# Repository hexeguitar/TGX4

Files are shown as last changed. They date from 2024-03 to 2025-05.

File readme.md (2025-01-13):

## TGX4 - Teensy Guitar Amp Project
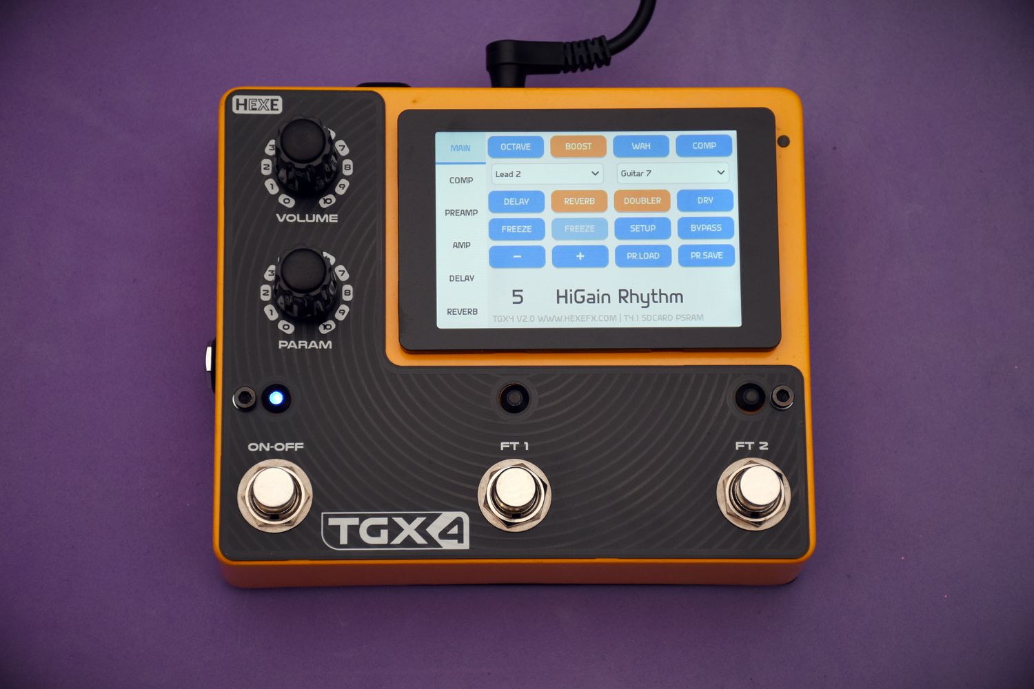
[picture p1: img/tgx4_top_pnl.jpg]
Top View
  

This project aims at creating a nice usable set of guitar and bass tones while using relatively inexpensive hardware and being simple to build.  
It combines a Neural Network amp modeler with stereo IR cabinet emulation, versatile stereo Ping-Pong delay and 3 different reverbs. There is also a Compressor, Wah and Booster with octave up mode for further input tone shaping.  

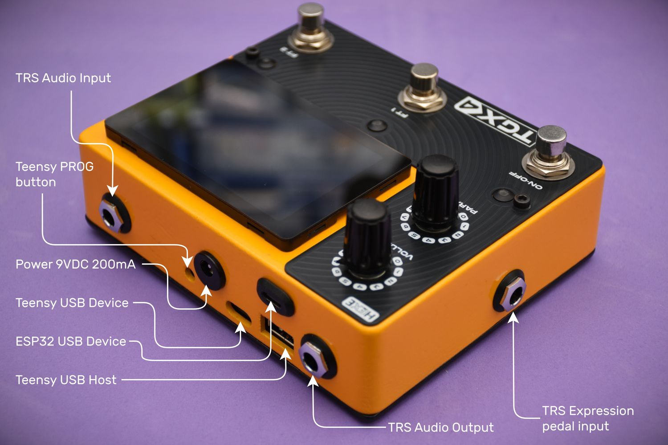
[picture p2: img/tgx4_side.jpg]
Side View
  

### Change-log  
V2.1 - 12-2024 - Added Front Panel, bug fixes  
V2.0 - 07-2024 - Dedicated hardware platform  
V1.4 - 04.2024 - Multiple hardware platforms added  
V1.3 - 03.2024 - Initial release.  

### User Interface  
#### HTML webpage
In general all the parameters are controlled via MIDI. There is a lot of controls and to make the hardware less expensive and easier to build the starting point is a simple html page using WebMIDI + WebSerial, which, opened in one of the supported browsers (Chrome, Opera, Edge) offers a full GUI interface.  
Teensy is using the USB Serial port to show the status and other info about the current state.  
Usage:  
1. Plug the Teensy with uploaded firmware into the USB port.
2. Open the TGX4.htm page (html folder) in any of the supported browsers.
3. Choose Teensy MIDI for the MIDI interface.
4. Click _Connect_ and choose the Teensy Serial port.
5. Press _Term_ button to switch between the status report and the CLI.
6. Use dials and buttons to control the effects.  

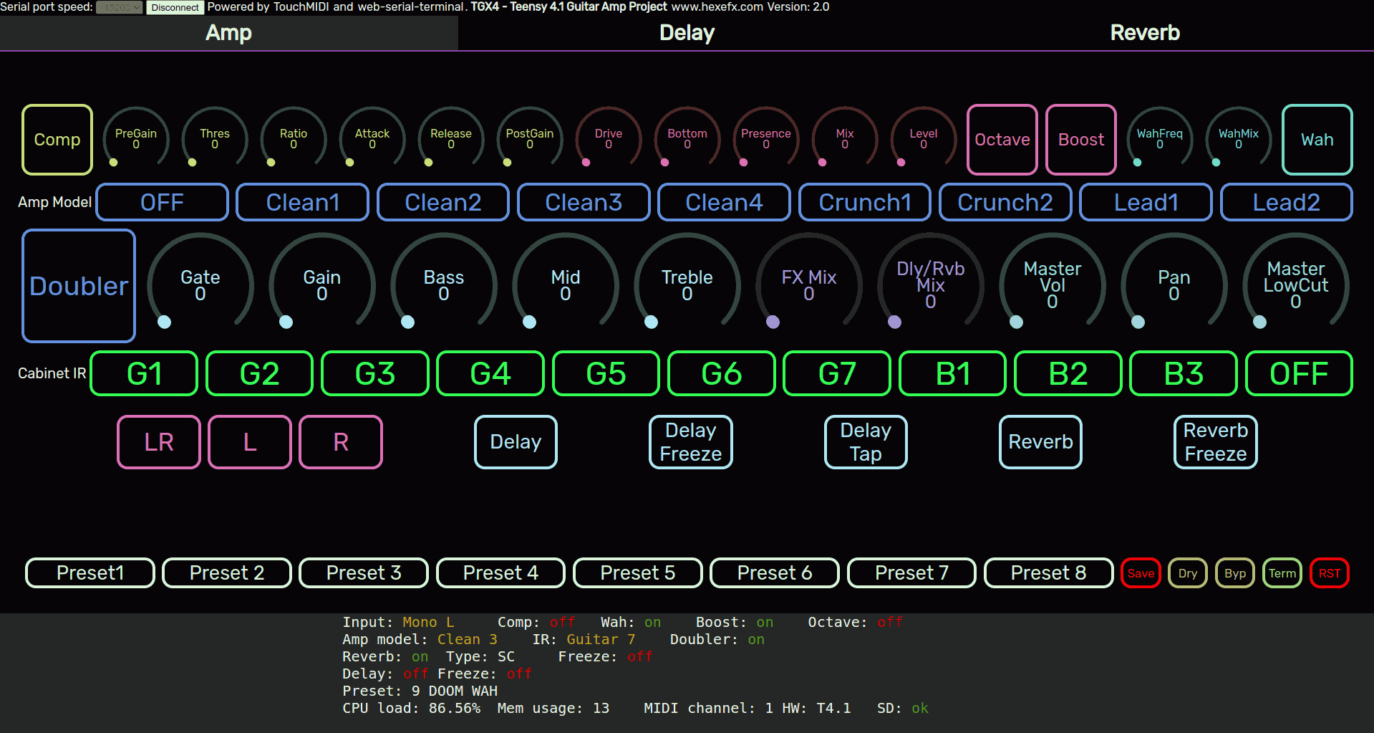
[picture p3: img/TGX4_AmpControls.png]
Ampinterface
  

#### Touchscreen GUI  
A separate project is provided for the **WT32SC01Plus board** (ESP32-S3 + 3.5" 480x320 IPS display, capacitive touchscreen) which is the main and dedicated user interface allowing access to all controls and functions of the pedal.  
The GUI is created using LVGL9 library:    

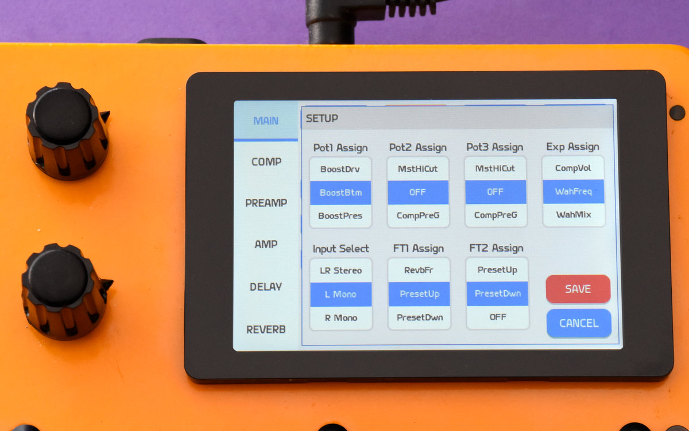
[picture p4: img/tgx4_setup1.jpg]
Setup
  
### Internal structure 

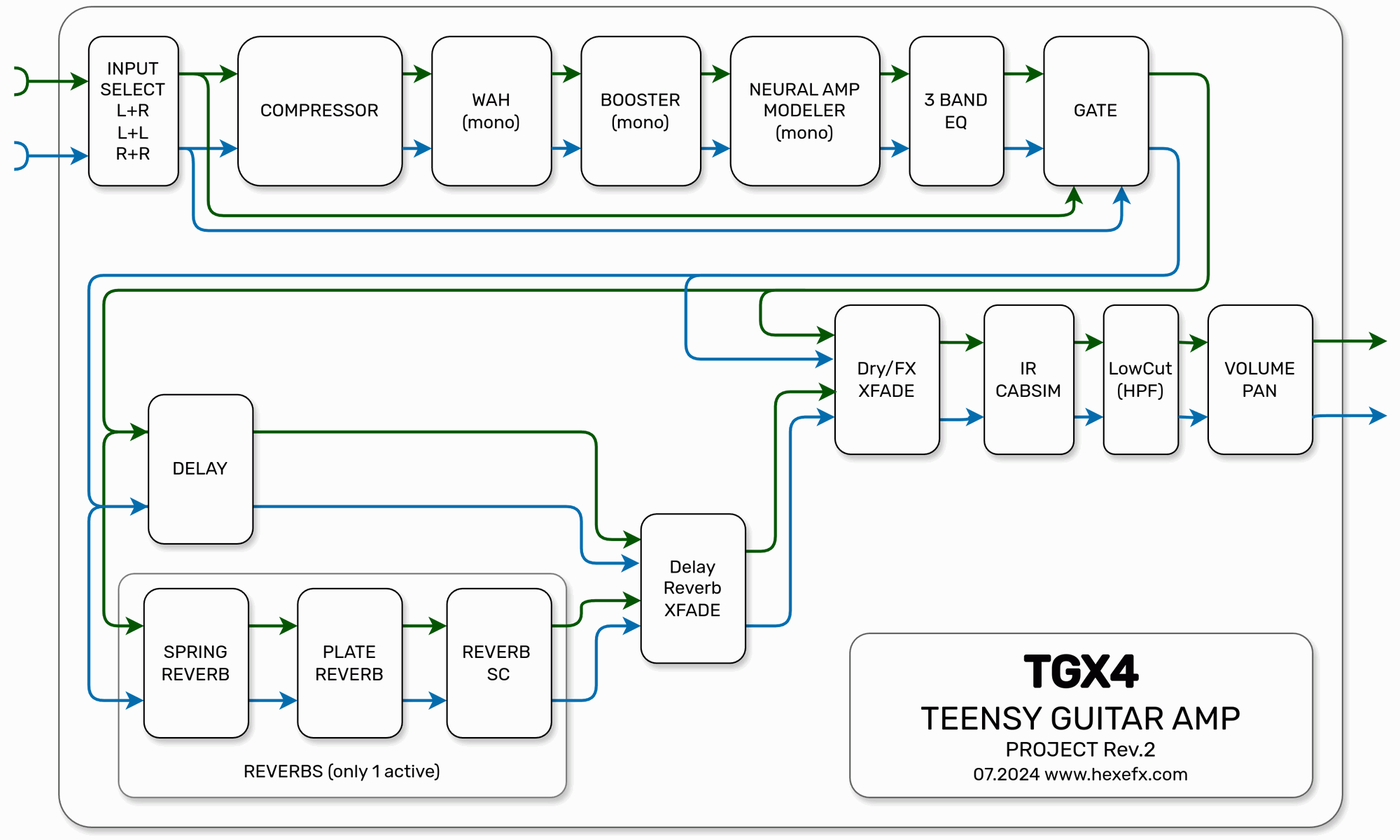
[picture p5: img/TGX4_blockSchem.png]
Internal structure
  

## Signal Flow  
The signal flow, except three components is stereo. The three mono components are: **Wah**,  **Booster** and **Neural Amp Modeler**. Mono means, these two sum the input signal into one and send one output to both L and R channels when enabled. In bypass mode both mono blocks pass the stereo signal unaffected. This way the TGX4 can be used either with mono source or as stereo effects processor (with Wah,  Booster and Amp Modeler disabled).
1. **Input Select** - controls which input channel use as source:  
	* L+R - stereo input
	* L+L - left mono input
	* R+R - right mono input
2. **Compressor** - stereo dynamic compressor with wide variety of controls:  
	* Pregain - input gain  
	* Threshold  
	* Ratio  
	* Attack, Release  
	* PostGain (MakeUp)  
3. **Wah** - mono wah implementation:  
	* 8 available models  
	* Frequency control  
	* Mix - dry/wet mixer  
4. **Booster** - an oversampled wave shaper based on 12AX7 tube curve:  
	* Drive - overdrive level  
	* Bottom - input highpass filter  
	* Presence - treble control  
	* Mix - dry/wet(distorted) mixer ratio, useful for Bass!  
	* Level - Booster output volume
	* Octave - analog octave up emulation  
5. **Neural Amp Modeler** 8 models available, from, clean channels, through light crunch to high gain lead ones:
	* Gain - controls the input signal level
6. **3 Band EQ** - this EQ is a "passive" one, meaning the flat response is when all controls are at max. Use for slight tone adjustments. Most of the "amp" sounds are already modelled in the previous block.  
7. **Gate** - adjustable Noise Gate. Noise gate is using the clean input signal for the side chain path, this way the threshold does not have to be adjusted for different distortion levels.
8. **Time Based FX Section** consisting of two effects in parallel: Stereo Ping-Pong delay with modulation and one of 3 available Reverbs. There are two main controls for this section:  
	* FX Mix - controls the dry sound vs Time FX sound mix ratio. Use to set the balance between the main sound and the Delay + Reverb combo  
	* Delay/Reverb Mix - this mixer controls the balance between the delay and reverb outputs.
9. **Stereo Cabinet Emulator / IR convolver**:  
	* 7 guitar cabinet models  
	* 3 bass cabinet models  
	* Stereo Doubler function emulating double tracking  
10. **Output Section**:  
      * Master Lowcut - output highpass filter to control the low end range  
      * Pan - Left/Right panorama setting  
      * Volume - final output volume   
  
### Stereo Ping-Pong delay  
One of the time based effects, versatile 1 second delay with modulation and Freeze feature (looper mode). Controls:  
   * Time - delay time  
   * Inertia - how fast the delay time is updated after change. Creates weird pitch shifting effects  
   * Repeats - amount of feedback  
   * HiCut - low pass filter inside the delay path, controls the treble loss for each repeat. Many delays implement such feature and claim to make the sound "analog"  
   * LowCut - high pass filer inside the delay path, controls the bass loss for each repeat  
   * Treble - overall treble control to make the sound darker
   * Bass - output bass control for further delay tone shaping  
   * ModRate - modulation rate (internal LFO speed)
   * ModDepth - modulation depth (internal LFO depth)
   * Tap Tempo  
   * Freeze mode - mutes the input signal and lets the echo repeat infinitely  

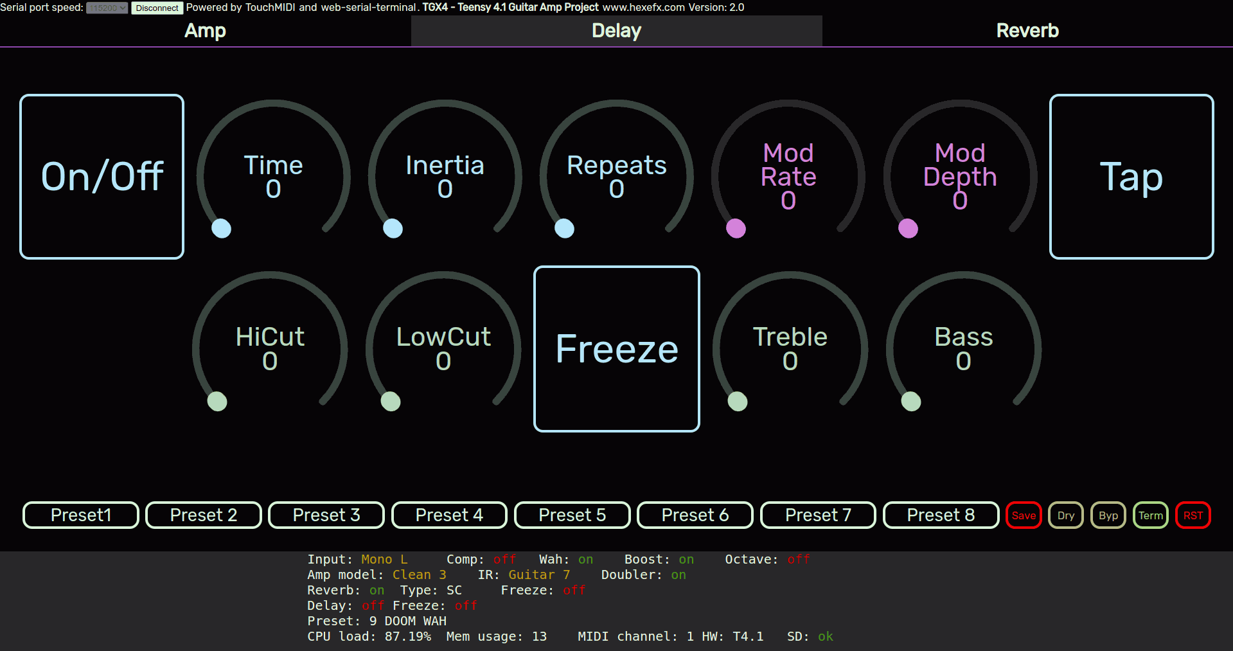
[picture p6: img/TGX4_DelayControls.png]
Delay controls
     

## Reverb Section  
There are 3 types of reverb built in, **only one can be active** at a time:  
1. **Plate Reverb** - versatile lush sounding long reverb:  
	* Size - reverb time  
	* Diffusion - lower values create more echo effects inside the reverb tail  
	* Treble Cut - treble loss in the reverb tail, affects the reverb time  
	* Bass Cut - bass loss in the reverb tail, affects the reverb time  
	* Treble - output treble control for the reverb wet signal  
	* Bass - output bass controls fot the reverb wet signal  
	* Pitch - reverb pitch set in semitones (range -12 to +24)  
	* Pitch Mix - mix ratio for the pitched up/down and natural pitch signal (creates harmonies)  
	* Shimmer - amount of shimmer effect  
	* Pitch Shim - shimmer effect pitch setting  
	* Freeze mode - creates infinite reverb sound  
	* Bleed In - amount of input signal fed into the reverb while in Freeze mode.  
2. **Reverb SC** based on Sean Costello's reverb algorithm using multiple feedback delay lines *(available only with PSRAM installed)*:  
	* Time - reverb time  
	* Lowpass Freq - tail treble loss  
	* Freeze mode - infinite reverb sound  
3. **Spring Reverb** - for more classic guitar tones, emulation of a typical spring reverb tank:  
	* Time - reverb time  
	* Bass Cut - high pass filter
	* Treble Cut - lowpass filter  

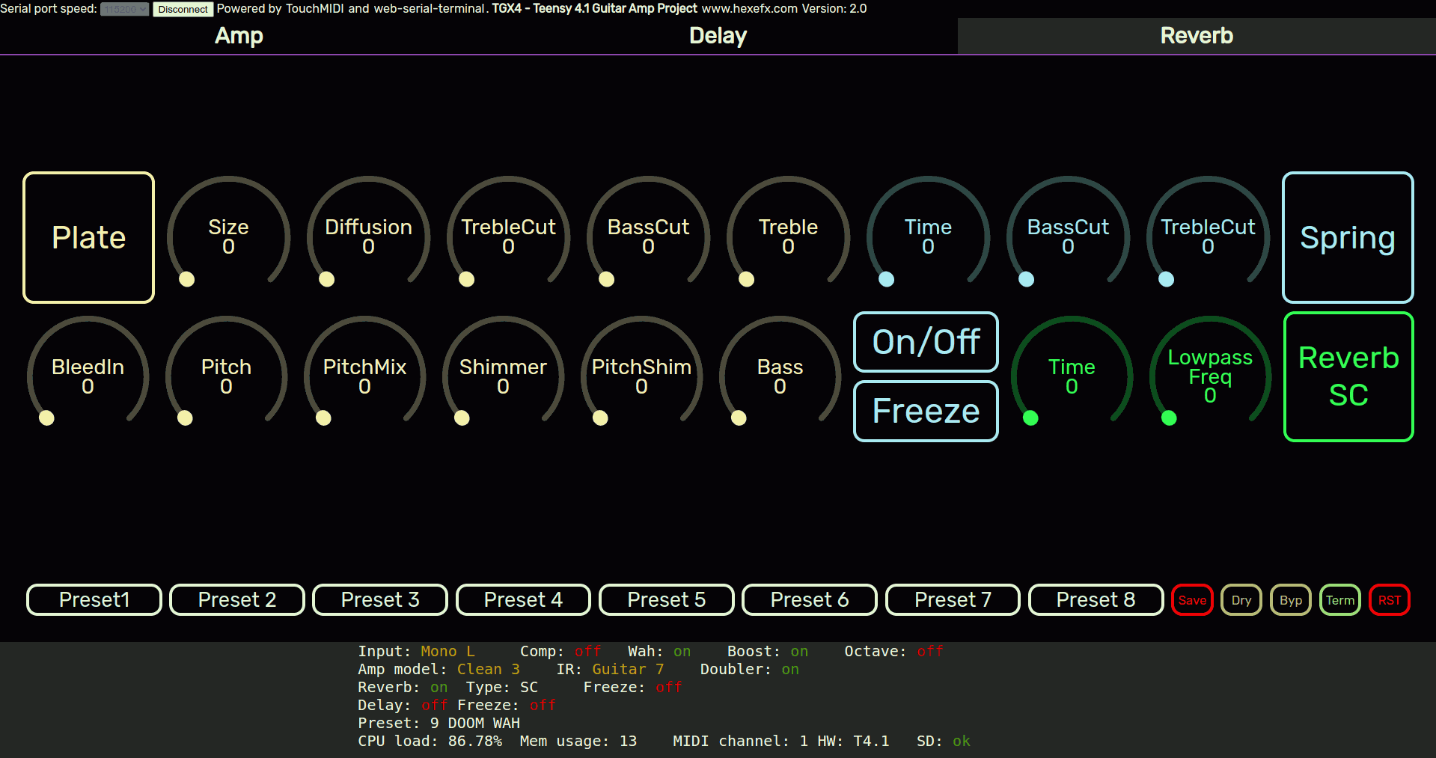
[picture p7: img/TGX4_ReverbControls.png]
Reverb controls
   

Press **Plate**, **Spring** or **ReverbSC** button to activate the reverb.  

## Hardware  
In the simplest form, this project can run on a Teensy 4.0 or T.4 and the audio adapter board.  
Adding PSRAM to the Teensy4.1 opens up the full set of features. Lack of PSRAM results in:  
- ReverbSC disabled,
- Delay has a shorter time range.  
  
Recommended upgrade would be a high impedance input buffer using an opamp or even a simple transistor one.  
See [**here**](diy_buffer.md) for a simple DIY project. 
Alternatively, another pedal with buffered bypass can be used instead.  

The hardware build option is set either in the `platformio.ini` file  
`default_envs = t40_audio_board`  
or by invoking the build command from the terminal:  
`pio run -e t40_audio_board`  

List of pre configured hardware platforms as of July 2024:  
- `hexefx_tgx4` - Dedicated hardware platform for this project using 32bit AKM converters.
- `t40_audio_board` - Teensy4.0 + Audio Adaptor Board  
- `t41_audio_board` - Teensy4.1 + Audio Adaptor Board 
- `t40_blackaddr_tgapro` - Blackaddr TGA Pro + Teensy4.0  
- `t41_blackaddr_tgapro` - Blackaddr TGA Pro + Teensy4.1   
 
The project is designed to be easily adaptable to many Teensy based hardware platforms, take a look [**here**](hw_platform.md) for more details.  
### Caution!  
A high gain sound, like the Preset 5 might and do create a feedback and oscillation on some of the hardware platforms, namely the SGTL5000 and ES8388. The noise gate can cut it off, although some oscillation will be audible when the gate closes.  WM8731 seems to be more immune to oscillations.  
A very high gain devices require a careful layout and design to make them as silent as possible. It is also a reason for designing a dedicated HW platform for the TGX4 project which incorporates design techniques to minimize these issues.  
## TGX4 Hardware  
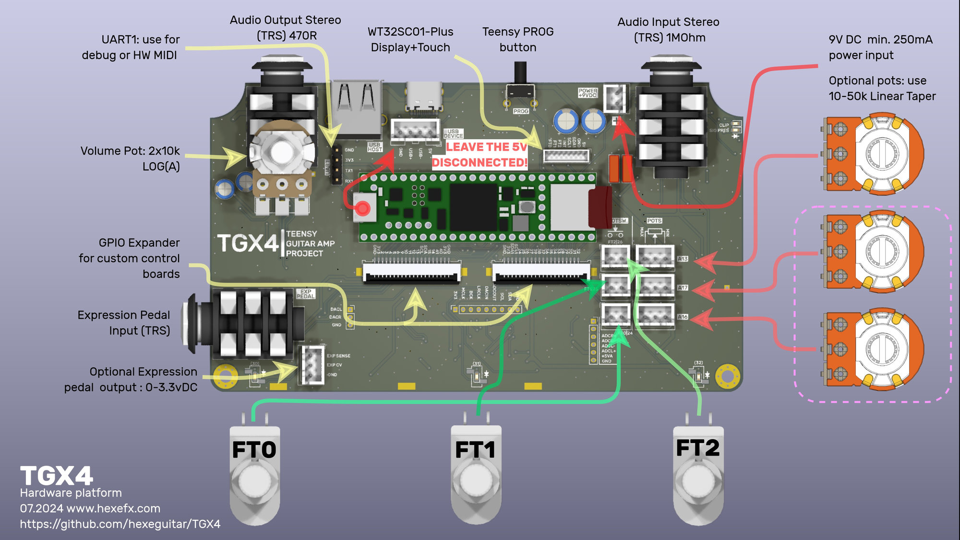
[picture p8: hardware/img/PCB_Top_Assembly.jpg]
   
 Dedicated TGX hardware platform project is available in the `hardware/`  folder.  

## Usage  
1. Open the **TGX4_TeensyMainBoard** project in the PlatformIO environment.
2. Open the `platformio.ini` file and set the required hardware configuration.
3. Build the project and upload it to the Teensy4 board.
4. Open the **TGX4_WT32SC01PLUS_GUI** project in the PlatformIO environment.
5. Build the project and upload it to the Display board.
6. For the web page access open the `TGX4.html` file placed in the `html` folder in Chrome, Chromium or Edge browser (others do not implement WebMIDI and WebSerial).
7. Connect to the USB MIDI interface listed as Teensy.  
8. Click `Connect` button on the top of the page and choose Teensy Serial port.
9. Use the dials and buttons to control the device.  

## Preset System (no display version)
A snapshot of all controls (except Delay+Reverb Freeze modes) can be saved in 128 available preset slots. Preset System is using the SD card to store the files. If no SD card is detected, the number of presets is limited to 8, stored in EEPROM.
1. Choose the Preset slot by pressing the buttons **Preset 1** - **Preset 8**. Alternatively use the CLI console to load preset numbers over 8 using the command `preset-load n`, where `n` is the preset number in range 1-128.
2. Set a new name for the preset using the `preset-name xxxx` CLI command.
3. Press **Save** to store the current sound in the chosen preset.  

## Preset System (using the display GUI)  
Switching the presets can be done in two ways:  
1. Using the **+** and **-** buttons on the touch screen MAIN page. The new preset is loaded immediately. To reload the preset from the saved file (ie. restore to saved version) press the **PR.LOAD** button.
2. Using the footswitches. The default function of the middle footswitch is **Preset UP**, the right one **Preset DOWN**. Pressing one of the footswitches enables browsing through the presets without loading them. To activate the chosen preset press and hold down one footswitches (usually the last used one). Browsing is shown as a popup window with the number and the name of the preset.  
   
## Default Presets  
1. Clean guitar sound, spring reverb.
2. Lightly overdriven clean guitar sound with modulated delay used as a stereo chorus.  
3. Boost/Overdrive into Clean channel + Reverb SC. Uses Stereo Doubler to emulate double tracking. Bluesy rhythm tone.  
4. Crunch Amp + Boost, mono mode + stereo delay and reverb. Bluesy solo sound.
5. High gain rhythm tone, a bit of Spring Reverb, Stereo Doubler enabled.  Uses Booster for input tone shaping, low end cut and light overdrive.
6. High Gain solo tone with modulated delay and reverb.  
7. Clean Bass sound with compressor.
8. Distorted fuzzy stereo bass sound.  

## Demos  
https://www.youtube.com/watch?v=2hztEZ9_kYk  
Watch the video (https://youtu.be/2hztEZ9_kYk)  

https://www.youtube.com/watch?v=AlLRwmOwigU  
Watch the video (https://youtu.be/AlLRwmOwigU)  

All guitar/bass sounds on this track were recorded using the TGX4:    


## Command Line Interface  
Use the **Term** button places on the main **Amp** page to switch between the status report and the CLI. Type `help` to list all the commands. CLI uses history and autocomplete.  
Available commands:  
- `preset-rst` - repopulates the 128 (or 8 without the SD card) available presets with default "factory" ones.  
- `preset-name` - sets the new name for the current preset. Argument: name, max 15 chars. Eg. `preset-name Solo-Delay`
- `preset-load` - loads the preset, argument: preset number 1-128.
- `preset-backup` - creates a copy of the 128 presets data in a separate `backup` directory on the SD card.
- `meminfo`- print RAM memory details  
- `load`- list CPU loads for all components  
- `midi-ch`- assign a new MIDI channel for the Teensy. Use it when controlling the device with other MIDI controllers. The WebMIDI interface sends the data on channel 1.  
- `i2c` - I2C scanner, takes one parameter: 0, 1 or 2 (Wire, Wire1, Wire2) and reports all found devices.
- `list` - lists all the files found on the SD card.

## Credits  
The Neural Network Modeler is based on implementation by [Keith Bloemer/GuitarML](https://github.com/GuitarML/Seed)  

[OpenAudio_ArduinoLibrary](https://github.com/chipaudette/OpenAudio_ArduinoLibrary) by Chip Audette  

[embedded_cli](https://github.com/funbiscuit/embedded-cli) by Sviatoslav Kokurin.

---  
(c) 2024 by Piotr Zapart  
www.hexefx.com

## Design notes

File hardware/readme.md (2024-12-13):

## TGX4 Dedicated Hardware Platform  
### Features:  
- Stereo input/output, electronic (FET) bypass  
- Analog Dry/Wet mixer  
- 32bit 44.1kHz ADC + DAC
- Optional codec module replacing the default ADC+DAC  
- Flexible control interface options, default: TFT+Touch screen (W32SC01_plus)  
- Analog signal presence and clip indicator  
- Teensy4.1 as main DSP
- Expression pedal input (can be used as 0-3.3V CV input)
- 3 configurable footswitches
- up to 3 configurable pot (default: 1)  
- 3 leds  
- USB device (MIDI + Serial - Teensy)
- USB host
- Enclosure: Hammond 1590XX  
---  
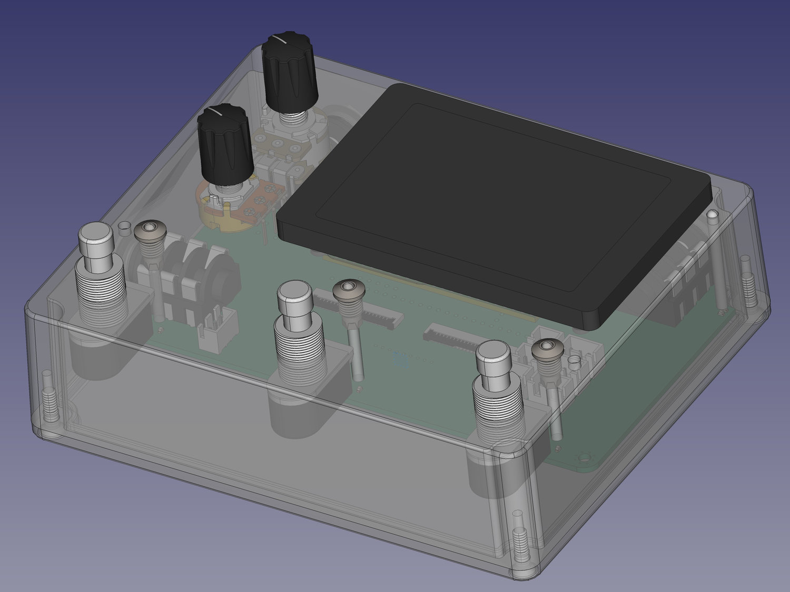
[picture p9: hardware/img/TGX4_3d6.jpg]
  
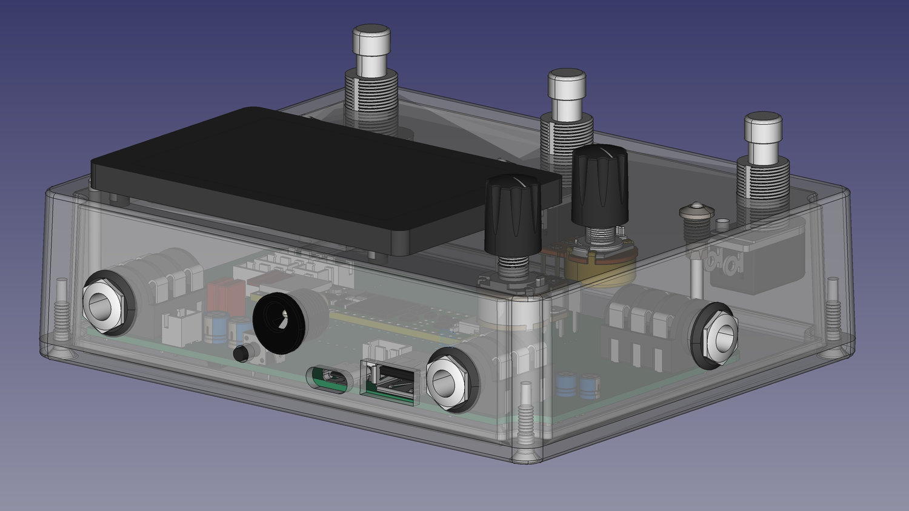
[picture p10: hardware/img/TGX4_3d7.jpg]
  
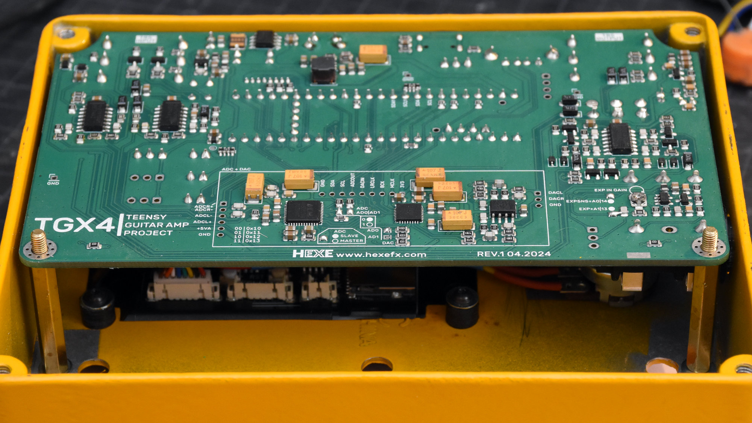
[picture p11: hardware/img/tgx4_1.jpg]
  

### Assembly  
  
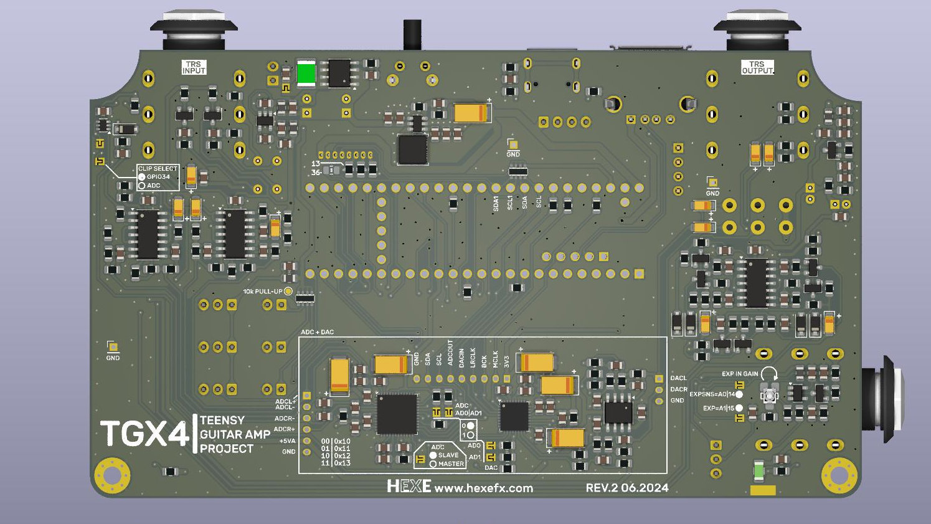
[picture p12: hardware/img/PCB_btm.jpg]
  

### Building  
#### 1. Main PCB  
KiCad project is provided in the `KiCad_proj/MainBoard` folder.  
The main PCB is a 4 layer one. A zip file with Gerbers is included and can be used to order a set of the boards. I do recommend ordering a stencil for the bottom layer.  
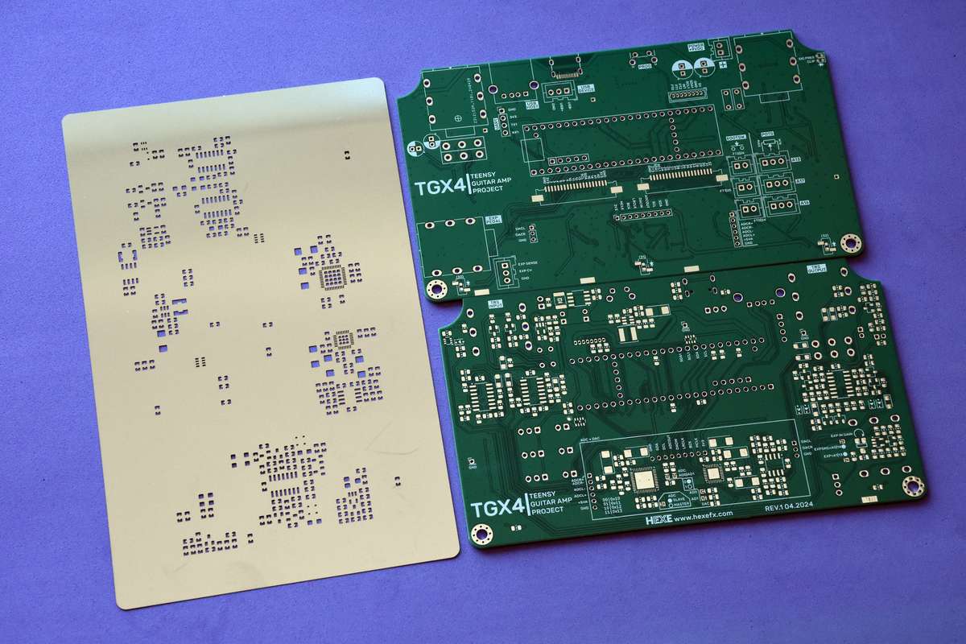
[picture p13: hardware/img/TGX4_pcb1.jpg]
  

Interactive HTML BOM is available and will help with hand placing the components. Most of the passives are 0805 and larger.  
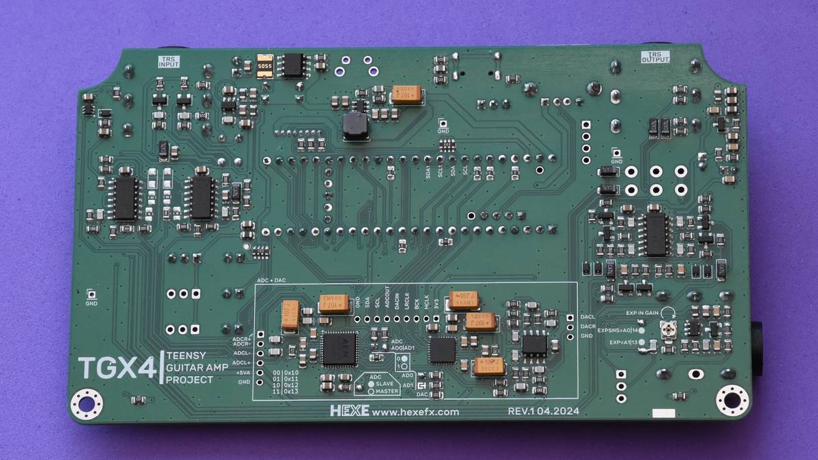
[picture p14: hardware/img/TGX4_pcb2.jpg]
  

There are various jumpers included on the main PCB. They are pre-set for default configuration.
1. **CLIP SELECT** The AK5552 ADC has an input signal clip indicator which is used to drive the red part of the SignalPresence/Clip indicator. This might not be the case for other codecs/ADCs. Signal Clip line can be also driven directly from Teensy's **GPIO34**. To enable it the jumper has to be bridged. Default source is the ADC.  
2. **ADC MASTER/SLAVE** selector. Default setting is Slave - Teensy generates all the required I2S clocks.  
3. **ADC ADDR** I2C address used to configure the AK5552 chip.  
4. **DAC ADDR** I2C address used to configure the AK4452 chip. 
5. **13/36** near the display connector. Footswitch signals are routed to the ESP32S2 board, one can be swapped for the GPIO36 and used for other tasks.  
6. **EXPSNS=A0|14** Expression pedal detection is routed to GPIO14 (default). To free the GPIO14 when no expression pedal is used, make the jumper open.  
7. **EXP=A1|15**  Expression pedal signal. By default routed to GPIO15 (jumper closed).  
8. **10k PULL-UP** a test point providing a 10k 3.3V pull up resistor in case it's needed. 

Top layer are mainly through-hole components, except the USB-C connector for the Teensy and the LEDs.  
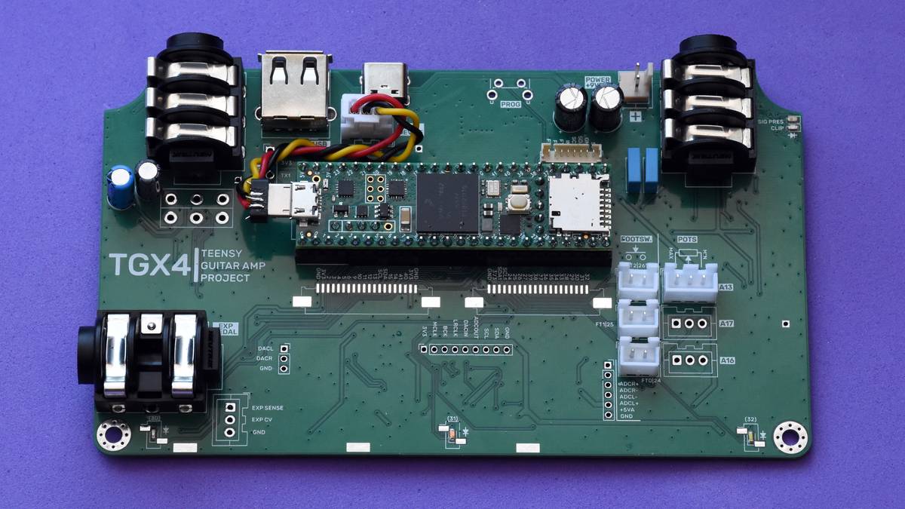
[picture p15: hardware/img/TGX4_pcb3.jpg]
 
### Caution!  
<h2><span style="color:red;">While connecting the Teensy and the ESP32 to the USB sockets leave the VBUS 5V wire disconnected!</span></h2>  

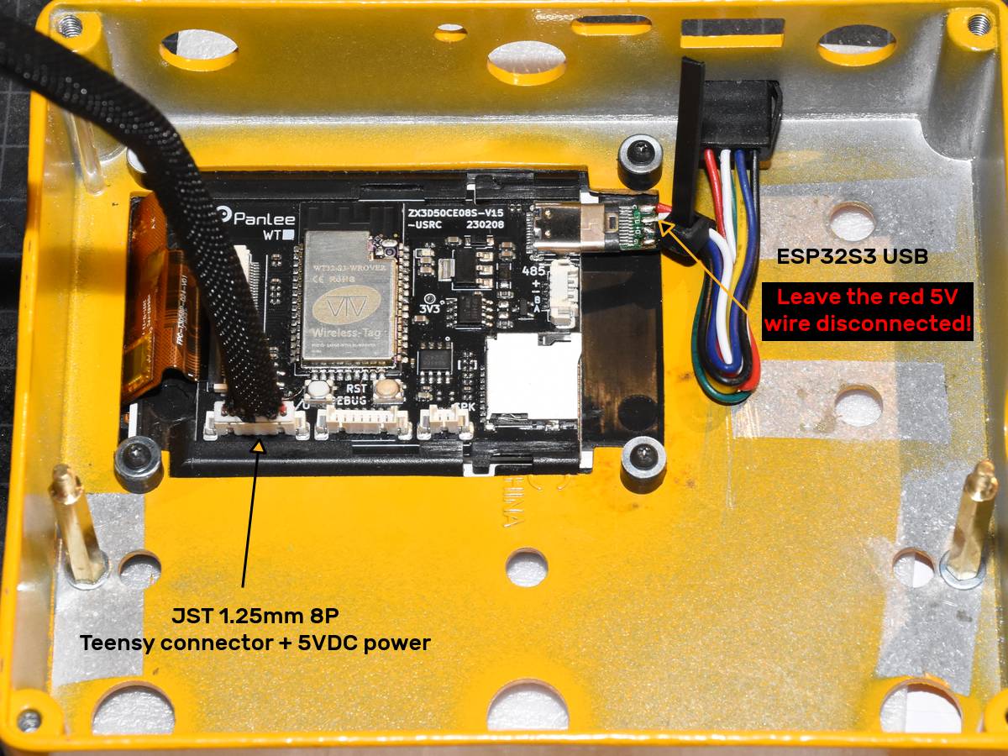
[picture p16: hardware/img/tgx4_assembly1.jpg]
 
#### 2. Making the enclosure  
See [>>>> here <<<<](enclosure.md).  

### Front Panel  
Front panel as KicaD PCB project, including gerbers is available in the `KiCad_proj/FrontPanel` folder.  
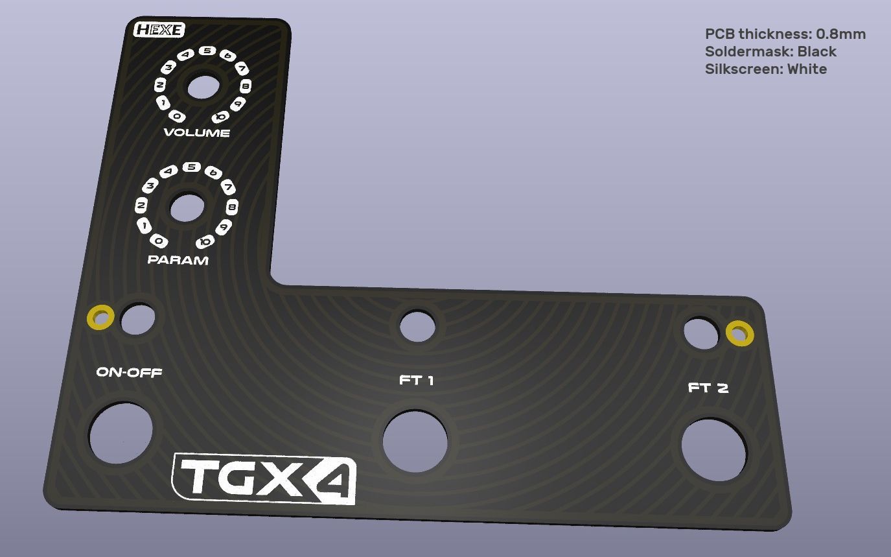
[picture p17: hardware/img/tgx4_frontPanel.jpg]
   

### Display  
The ESP32S3 + Touch display board used in this project is the WT32SC01Plus. There are many variants of the ESP32+display boards floating around, here are the specs of the used one:  
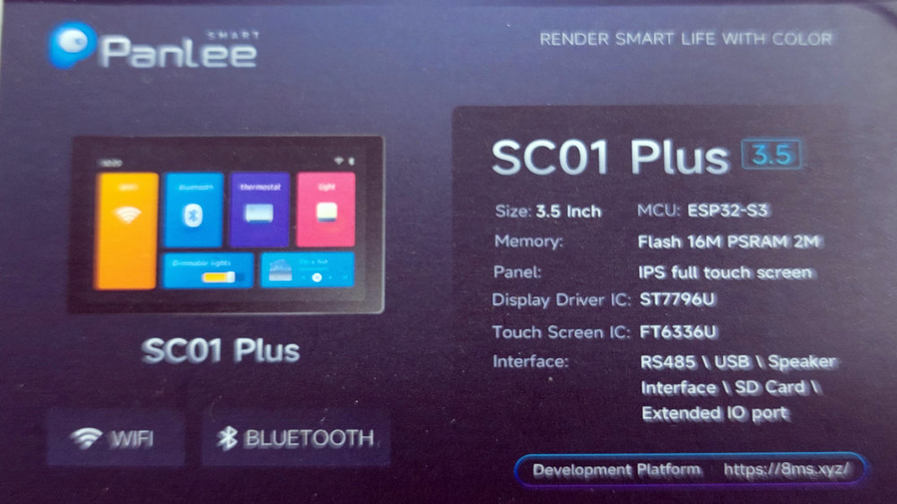
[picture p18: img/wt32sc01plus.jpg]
Control interface
  

----  
Copyright (c) 2024 by Piotr Zapart  
www.hexefx.com  

[img_3d1]: img/TGX4_3d6.jpg "Render 1"
[img_3d2]: img/TGX4_3d7.jpg "Render 2"
[img_pcb1]: img/tgx4_1.jpg "PCB bottom view" 
[img_top]: img/PCB_Top_Assembly.jpg "Assembly top" 
[img_btm]: img/PCB_btm.jpg "Bottom view"

[img_pcb2]: img/TGX4_pcb1.jpg "PCB"
[img_pcb3]: img/TGX4_pcb2.jpg "PCB"
[img_pcb4]: img/TGX4_pcb3.jpg "PCB"

[img_5]: img/tgx4_assembly1.jpg "Display assembly"

[img_6]: img/tgx4_frontPanel.jpg "Front Panel"

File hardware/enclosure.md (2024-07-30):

## TGX4 - making the enclosure  
TGX4 is designed to fit into a diecast aluminium box made by Hammond: model **1590XX**.  
A drill layout file in 1:1 scale is provided in the `Mechanical` folder.  
Build process (manual, no CNC):  
1.  Print out the drill layout and cut to size for all 3 surfaces.
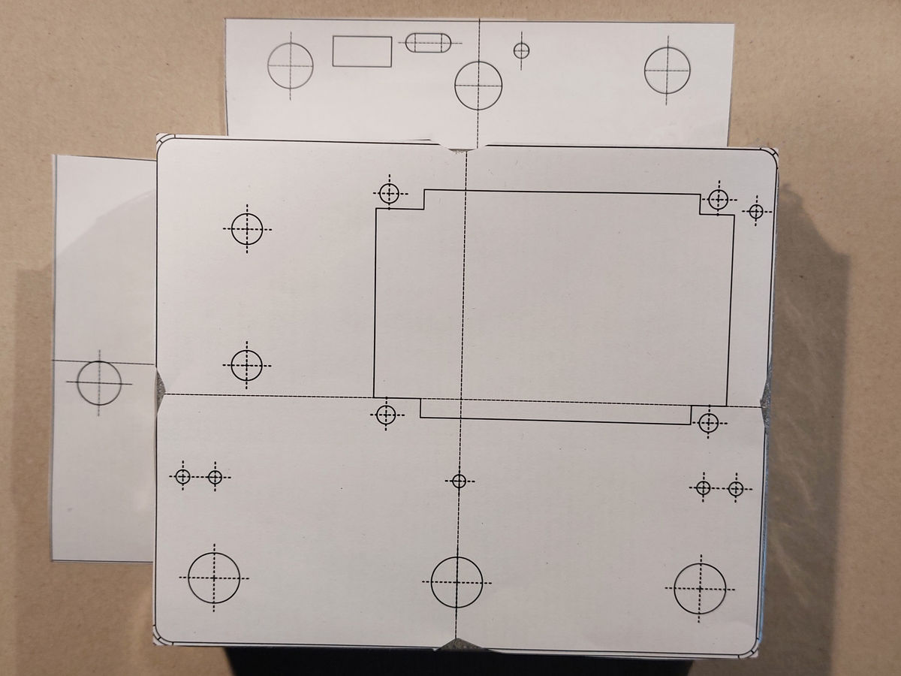
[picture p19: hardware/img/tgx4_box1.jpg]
  
2. Mark the center points on the sides of the enclosure.  
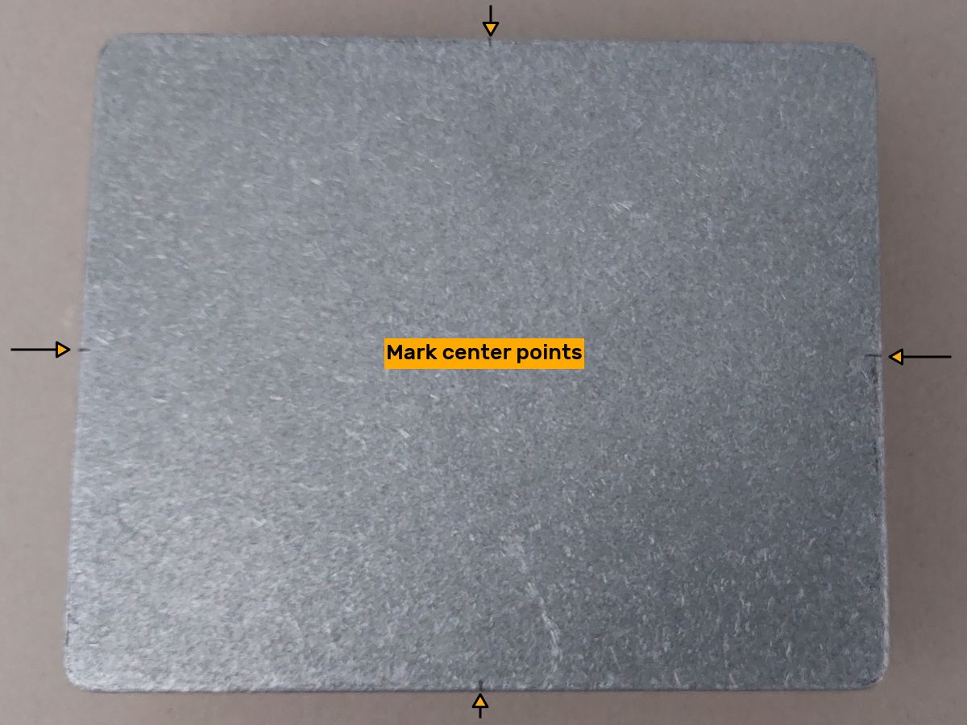
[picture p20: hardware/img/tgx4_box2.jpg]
  
3. Match the center lines with the marked points and fix the drill guide with a tape.
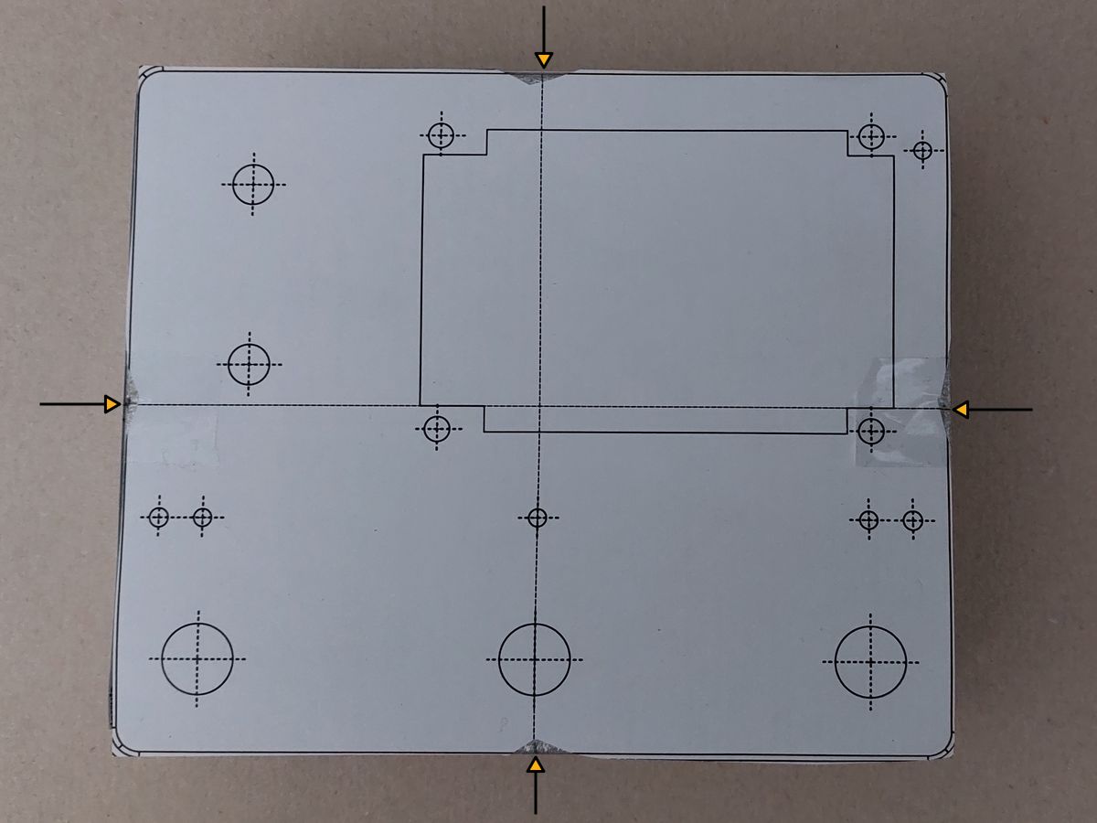
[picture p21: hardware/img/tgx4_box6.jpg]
  
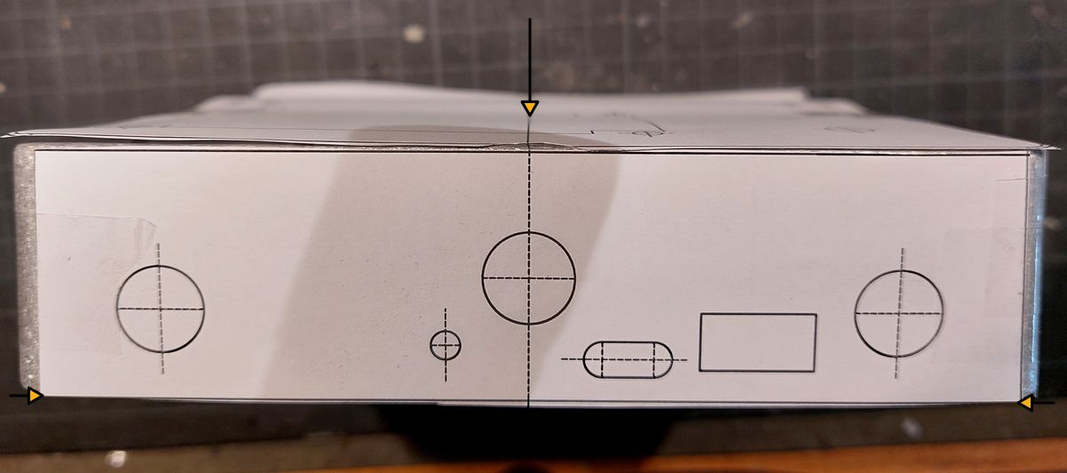
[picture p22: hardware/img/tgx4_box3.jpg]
  
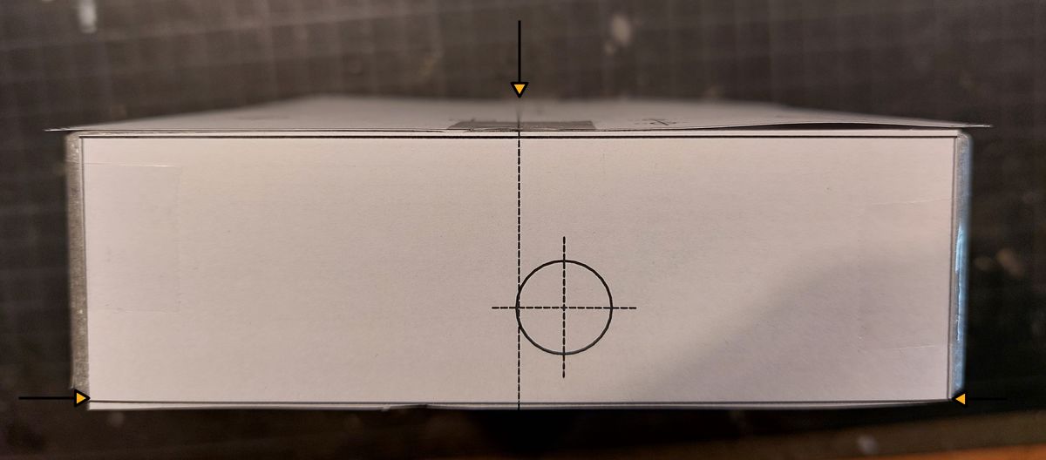
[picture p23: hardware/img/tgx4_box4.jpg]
  
4. Punch the center holes and mark the cutouts using a sharp knife or a scalpel.  
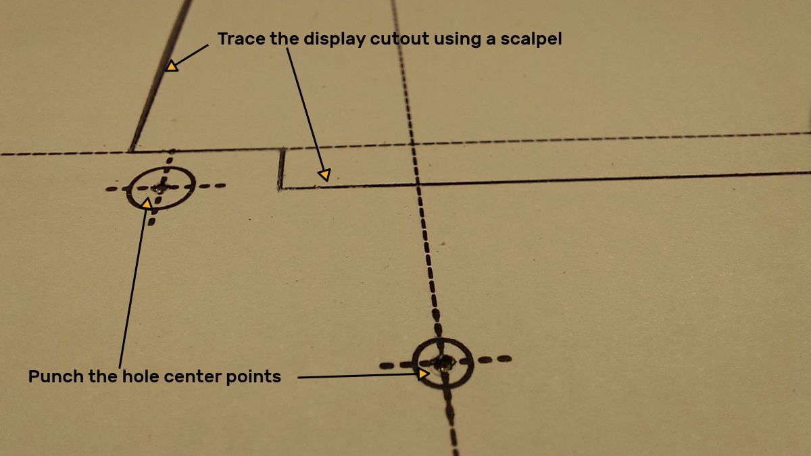
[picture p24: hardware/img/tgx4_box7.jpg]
  
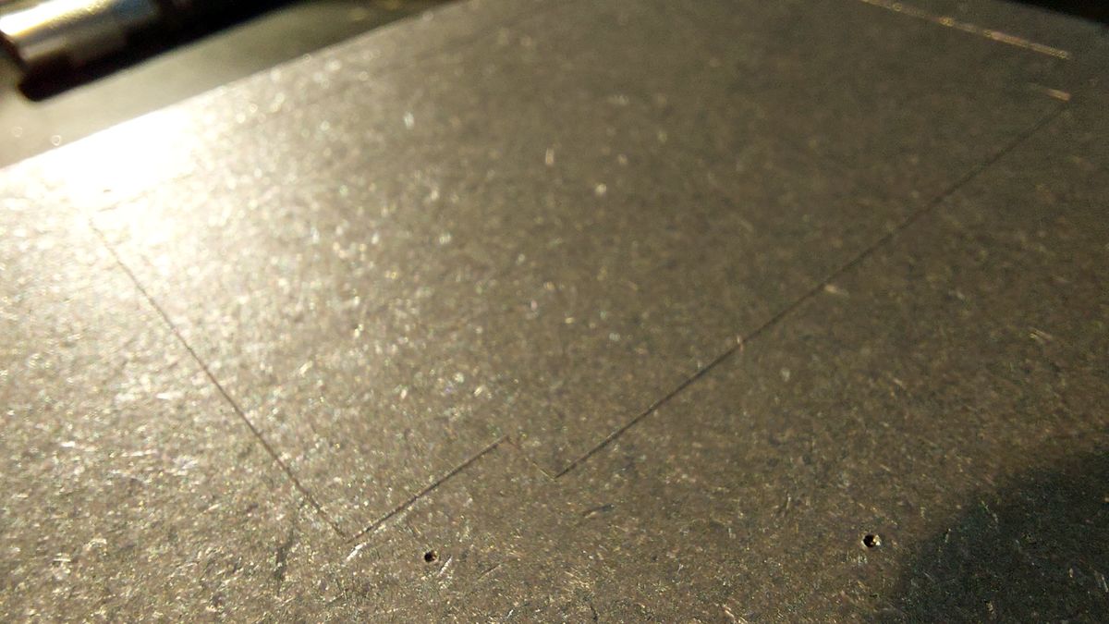
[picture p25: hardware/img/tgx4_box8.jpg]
  
5. Drill the holes and make the cutouts.  
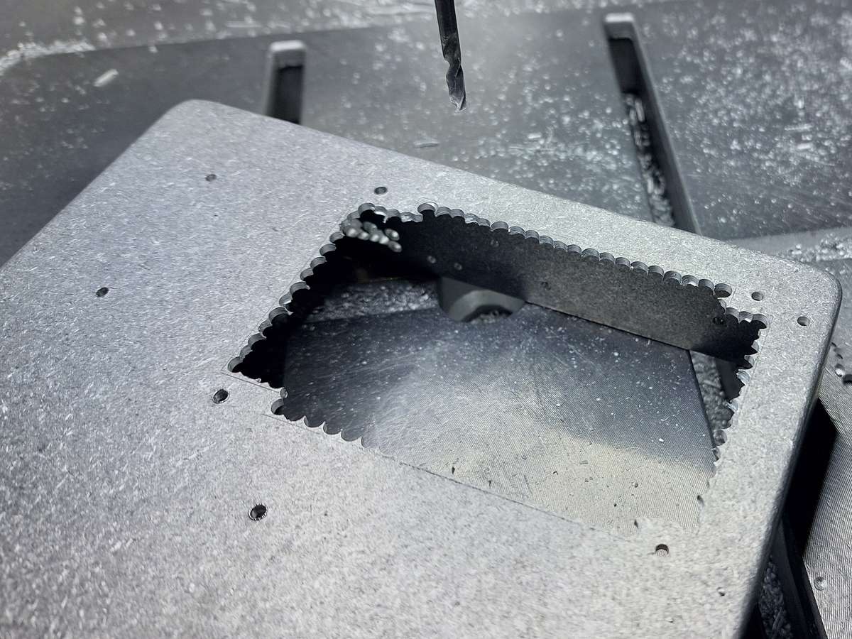
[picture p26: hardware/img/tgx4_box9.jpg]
  
6. Finished enclosure ready for painting.  
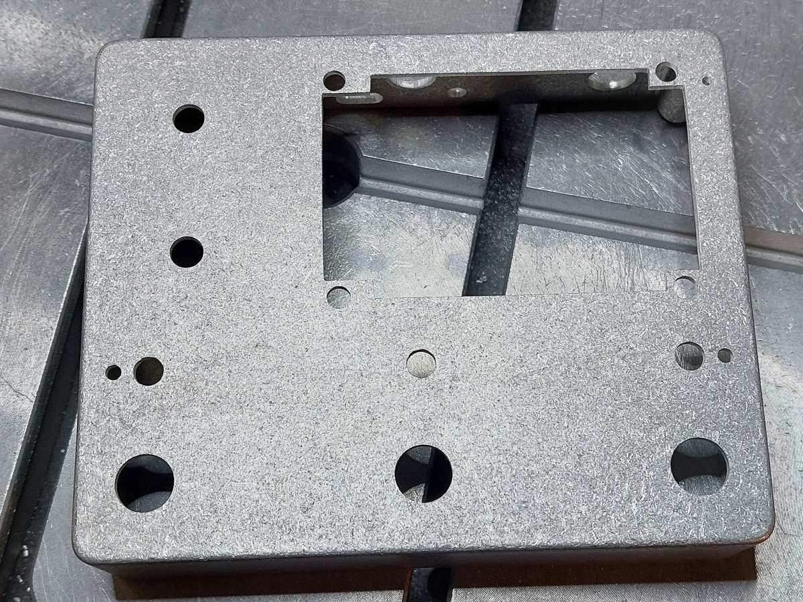
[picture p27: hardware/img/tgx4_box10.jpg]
  

---  
(c) 2024 by Piotr Zapart  
www.hexefx.com

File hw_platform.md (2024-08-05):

# Defining a new hardware platform  

Hardware platform for the TGX4 project consists of minimum one to two components:  #
1. Main board driver, defined in firmware as **hw** object. This part includes the Teensy and the audio system (codec or separate adc +dac).
2. Optional controller driver, defined in firmware as **gui** object. This can be a separate board with pots and switched or as in case of the dedicated hardware, the ESP32S3 board + touch display.  

### Hardware platform class  

Minimum requirements for a custom hardware driver are:  
1. Codec chip driver configured with the following settings:  
	- Sampling frequency: 44.1kHz
	- Master clock = 256 * Fs
	- 32bit left justified word (I2S format)
2. Optional GPIO configuration if the board uses analog switching for bypass, dry and wet signals.  

Take a look at the `hw_template.h` file in the `hardware_defs` folder.  
Contrary to the classic Teensy AudioLib auto generated code, a codec class (ie. *AudioControl_SGTL5000*) is a private member of the hardware platform class.  

A hardware platform class has to implement the following methods:  
- `bool init(void)` -  initializing the codec and if required other peripherals, GPIOS used for switches, pots and other control elements.  
- `bool dry_set(hw_state_t newState)` - used to externally switch the DRY signal. Often it can be a GPIO controlling an analog CMOS/FET switch or an already built in feature of the codec chip. If not used, should return `false`.  
- `bool dry_get()` - returns the dry signal switch state .
- `bool wet_set(hw_state_t newState)` - as above, only for the WET signal. Make it return `true` if not used, as in such cases the output is a WET signal only.  
- `bool wet_get()` - returns the wet signal switch state.  
- `bool state_set(hw_state_t newState)` - this is a master bypass switch. Normally it should switch off the WET signal and switch on the DRY signal if bypass is engaged. It can also be set to toggle the WET signal only if the device is used for time based effects only with the DRY signal always on.  
- `bool state_get()` returns the master bypass state.  
- `bool process(void)` - this method will be used for hardware tasks like reading switches, pots etc.  
- `bool phase_invert = false;` this variable sets the output phase. In some situations, like having an output MFB anti aliasing filters, which invert phase, it is convenient to flip it before the DAC. Set to true to enable output phase inverse.  

Create your own hardware class header+source file and put it in the `hardware_defs` folder.   
At the end of the header file add the preprocessor condition
```c++
#elif defined(USE_YOUR_CUSTOM_HARDWARE_PLATFORM)
	extern hw_YourCustomHardwarePlatform hw;	
#endif
```
The source file, in minimal version can be used to instantiate the class only:  
`yourCustomHardwarePlatform.cpp`:  
```c++
#include "yourCustomHardwarePlatform.h"
#elif defined(USE_YOUR_CUSTOM_HARDWARE_PLATFORM)
	hw_YourCustomHardwarePlatform hw;	
#endif
```
Next, include the new header file in the `hardware_defs.h` file.   
`USE_YOUR_CUSTOM_HARDWARE_PLATFORM` is a flag defined in the `platformio.ini` file and it controls which HW platform will the project be compiled for. 

```
[env:t40_es8388]
board = teensy40
build_flags = 
		${env.build_flags}
		-DUSE_CTRL_DUMMY
		-DUSE_I2S1
		-DUSE_ES8388	

[env:t41_es8388]
board = teensy41
build_flags = 
		${env.build_flags}
		-DUSE_CTRL_DUMMY
		-DUSE_I2S1
		-DUSE_ES8388	

; add new custom environment  
[env:your_custom_hw_platform]
board = teensy41	;or teensy4.0
build_flags = 
		${env.build_flags}
		-DUSE_YOUR_CUSTOM_HARDWARE_PLATFORM
		-DUSE_CTRL_DUMMY
		-DUSE_I2S1		; if using standard I2S
		;-DUSE_I2S2		; if using I2S2
		-DUSE_SGTL5000	; define which codec is used, optional

```  

### Controller/GUI class 
Similar to the HW platform class, this one creates a control interface.  
Required methods:  
- `void init(void)` -  initializing the controller and all it's used hardware.  
- `void process(void)` - processing the inputs, outputs, updating the parameters.  
- `void signalChage()` - used to inform the controller about a change or to confirm receiving a command.  

The header file should include the extern declaration of the class as **gui** object.
```c++
#if defined (USE_CTRL_CUSTOM)
	extern ctrl_custom gui;
#endif
```  
and the source file should instantiate it: 
`ctrl_custom.cpp`:  
```c++
#include "ctrl_custom.h"
#if defined (USE_CTRL_CUSTOM)
	ctrl_custom gui;
#endif
``` 
#### If no controller is required it has to be declared as DUMMY in the `platformio.ini` file:  
`-DUSE_CTRL_DUMMY`

----
Once all the files are in place change the default build environment to the new defined:  
```
[platformio]
default_envs = your_custom_hw_platform
```
Build and upload the project.  

## Tip for Linux users  
Working with two boards programmed via Serial port can be frustrating if they constantly change the serial port number. Luckily, the versatile udev on Linux comes with a helping hand and allows to create USB aliases. This way a device with a specified VID/PID can be accessed via a custom name instead of the direct /dev/ttyxx device.  
For this project, i have created a custom udev rules file  
`99-MCU_alias.rules`  
with the content:  
```bash
SUBSYSTEM=="tty", ATTRS{idVendor}=="16c0", ATTRS{idProduct}=="0489", SYMLINK+="ttyACM_Teensy4"
SUBSYSTEM=="tty", ATTRS{idVendor}=="303a", ATTRS{idProduct}=="1001", SYMLINK+="ttyACM_ESP32"
```  
and copied it to the /etc/udev/rules.d/ directory:  
`sudo cp  99-MCU_alias.rules /etc/udev/rules.d/`

Running `sudo udevadm control --reload` and re plugging the board makes them appear as `ttyACM_Teensy4` and `ttyACM_ESP32` no matter which `ttyACMx` port they are on.  

----  
Copyright (c) 2024 by Piotr Zapart  
www.hexefx.com

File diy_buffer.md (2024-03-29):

## Simple Stereo DIY audio buffer  
Here is as simple opamp based stereo buffer project which can be built on a piece of perfboard using through hole components. It provides a high impendace instrumental inputs for boards like the Teensy Audio Adaptor. Connect the buffer outputs to the stereo Line input of the Teensy Audio Adaptor.  
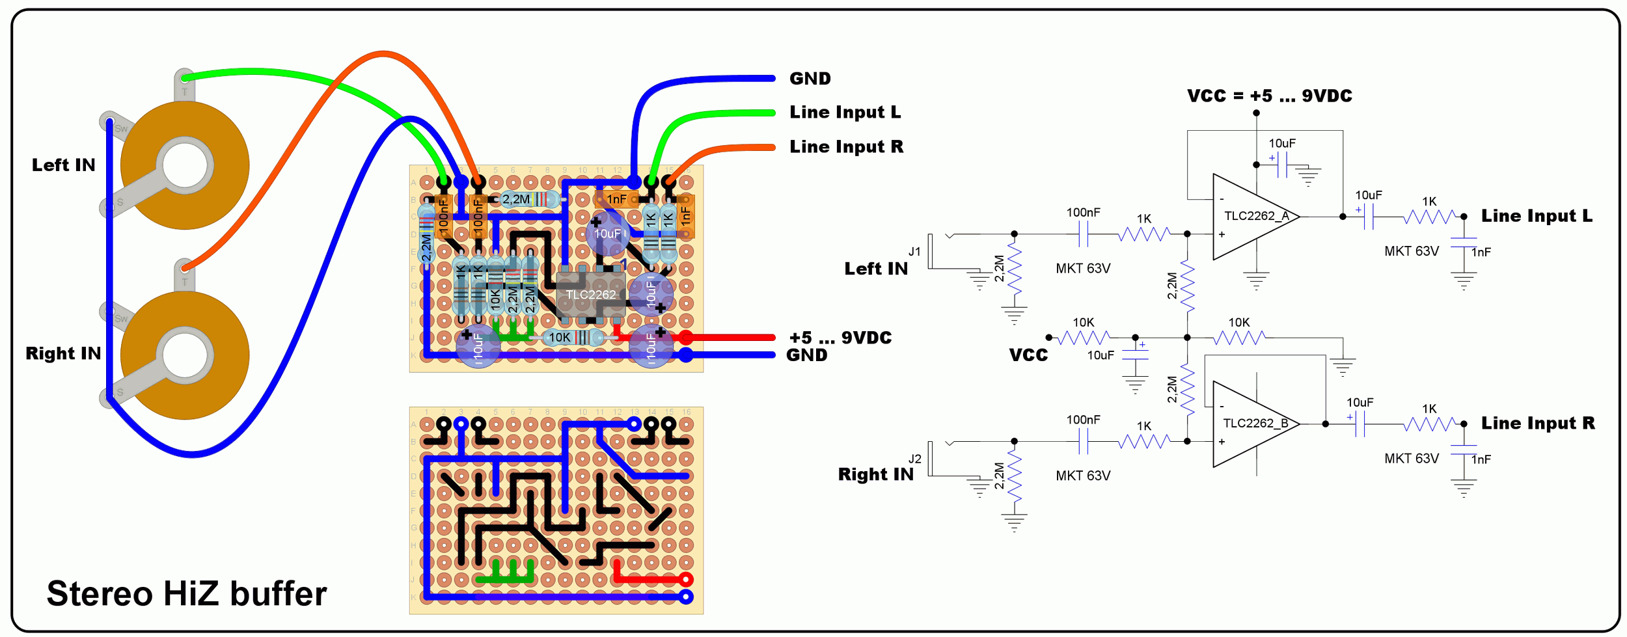
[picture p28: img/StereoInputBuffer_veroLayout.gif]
DIY stereo buffer
  
The TLC2262 (or TLC2272) dual opamp is a rail-to-rain IO one and can be used either with a 5V supply or a typical 9VDC adapter used for guitar pedals.

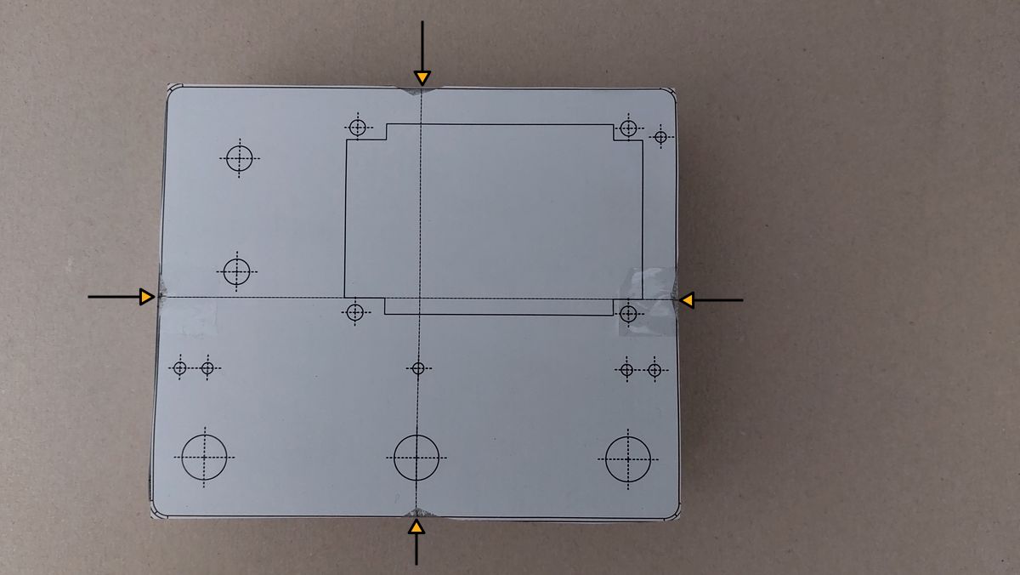
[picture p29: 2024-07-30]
hardware/img/tgx4_box5.jpg

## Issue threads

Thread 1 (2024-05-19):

hexefx_t41gfx i2s2 not working

darwin1234, 2024-05-19:
Hello,

I am trying to use I2S2 with the WM8731 audio codec from Open Music Labs, but it doesn't seem to be working.

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

Could you kindly share the details of your connection setup? Additionally, if you have any tips or common troubleshooting steps for this setup, I would greatly appreciate it.

Thank you!

hexeguitar, 2024-05-19:
Here is the Teensy pinout used with WM8731 and I2S2
```
I2S_MCLK:   33 (MCLK2)
I2S_BCK:     4 (BCLK2)
I2S_LRCLK:   3 (LRCLK2)
I2S_DACIN:   2 (OUT2) - WM8731 data in
I2S_ADC_OUT: 5 (IN2) - WM8731 data out

I2C_SDA:     18 (pull up 2k2)
I2C_SCL:     19: (pull up 2k2)
```

Troubleshooting:
1. Make sure the MCLK is present, it should be about 11.289MHz (44.1kHz * 256). Without it the WM8731 will not respond via i2c.
2. Check if the I2C can access the codec and configure it. The terminal window should output "Codec init fail" after reset in that case. You can also switch to the console window and run **i2c** command, it will scan all the devices on the I2C bus.**0x1A** is the codec's address.
3. Check the I2S bit clock, around 2.8MHz
4. Check the LRCLK, should be equal to the sampling rate: 44.1kHz
5. Check the data lines for activity

Oh - and in case you use the onboard jacks - the output is the headphone out. hexefx_t41gfx config uses Line outputs, headphone out is muted. However, there is no DC blocking present on the Audio Codec Shield and it has to be added externally. Otherwise there will be about 1.6V DC present on the line outputs.
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

Also - the interface is I2S, not SPI as in the description of the Codec Board. SPI can emulate I2S and it has been done on 8bit Arduinos. Teensy uses regular audio I2S interface. Judging from the pic, you have connected it to the SPI bus.

Hope it helps!

Closed 2024-06-25.

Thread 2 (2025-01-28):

[Question] T41.GFX

g40, 2025-01-28:
Great work here. Thanks.

Is the hardware shown in this video clip open source? https://youtu.be/VG3BTwthkws?

It would be grand to have an audio baseboard that included 1/4" audio sockets, MIDI and possibly a LAN jack, along with some buffering for guitar pickups.

Thanks for listening.

g40, 2025-01-28:
OK. I have just grokked that the KiCad design files are in fact for the T41.GFX? TIA.

Closed 2025-02-09.

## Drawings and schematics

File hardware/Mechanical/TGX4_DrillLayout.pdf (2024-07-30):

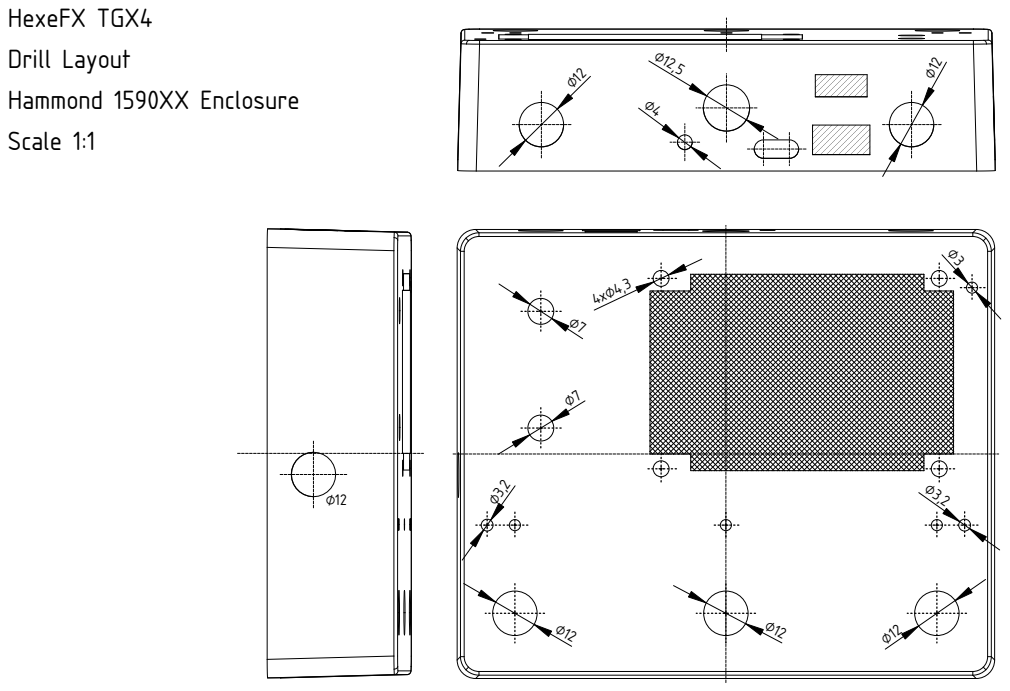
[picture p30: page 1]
HexeFX TGX4 Drill Layout Hammond 1590XX Enclosure Scale 1:1

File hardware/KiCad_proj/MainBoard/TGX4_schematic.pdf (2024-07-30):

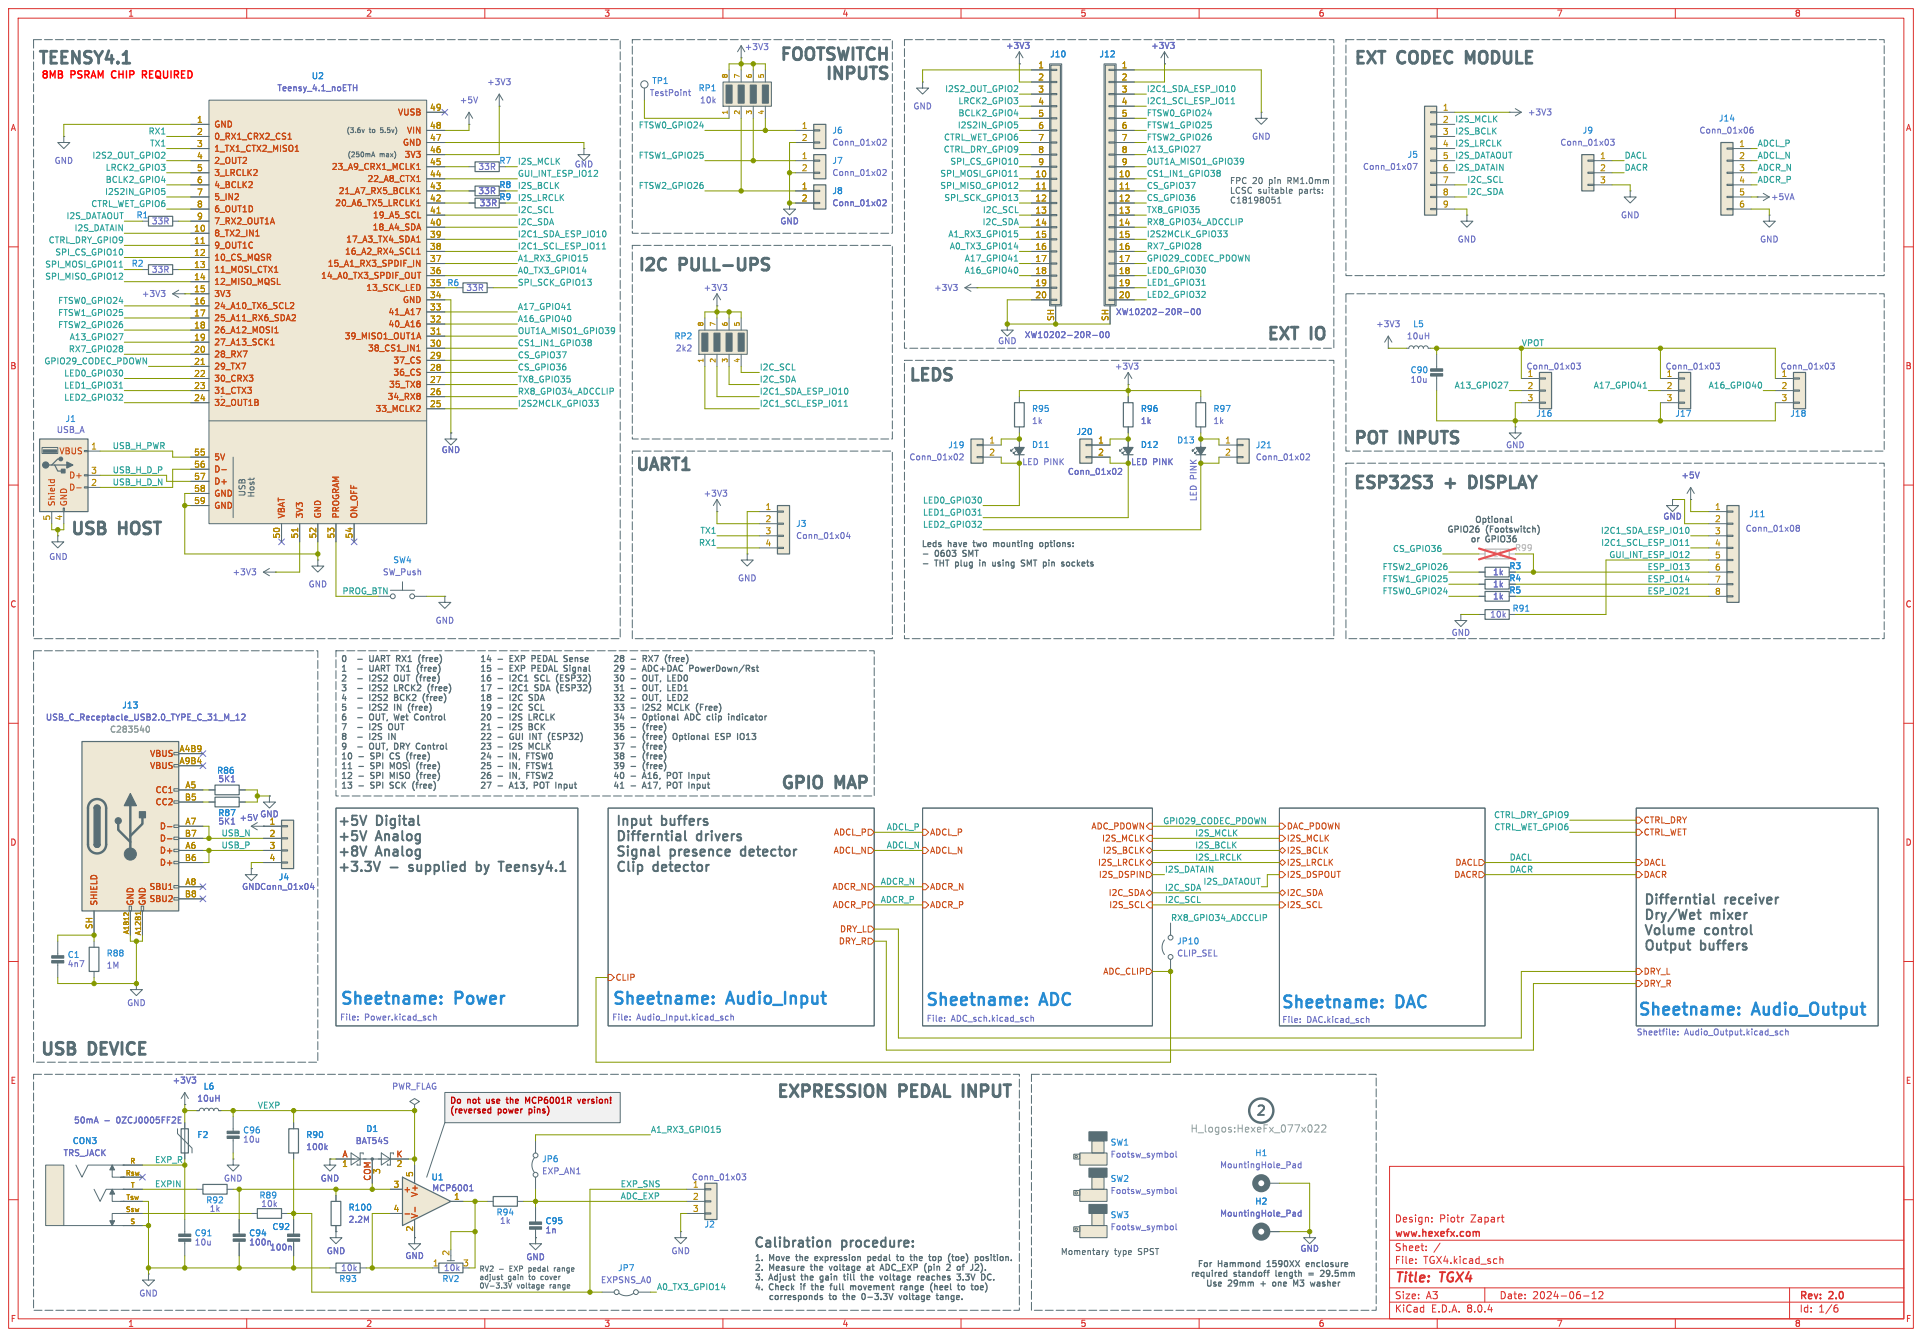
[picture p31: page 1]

- 0603 SMT
- THT plug in using SMT pin sockets

37 - (free) 38 - (free) 39 - (free) 40 - A16, POT Input 41 - A17, POT Input 14 - EXP PEDAL Sense
15 - EXP PEDAL Signal 16 - I2C1 SCL (ESP32) 17 - I2C1 SDA (ESP32) 18 - I2C SDA

28 - RX7 (free) 29 - ADC+DAC PowerDown/Rst 30 - OUT, LED0

31 - OUT, LED1
32 - OUT, LED2
33 - I2S2 MCLK (Free) 34 - Optional ADC clip indicator 35 - (free) 36 - (free) Optional ESP IO13

9 - OUT, DRY Control 10 - SPI CS (free) 11 - SPI MOSI (free) 12 - SPI MISO (free) 13 - SPI SCK (free)
VEXP USB_P
4 GND

Do not use the MCP6001R version!

File: TGX4.kicad_sch Sheet: / www.hexefx.com

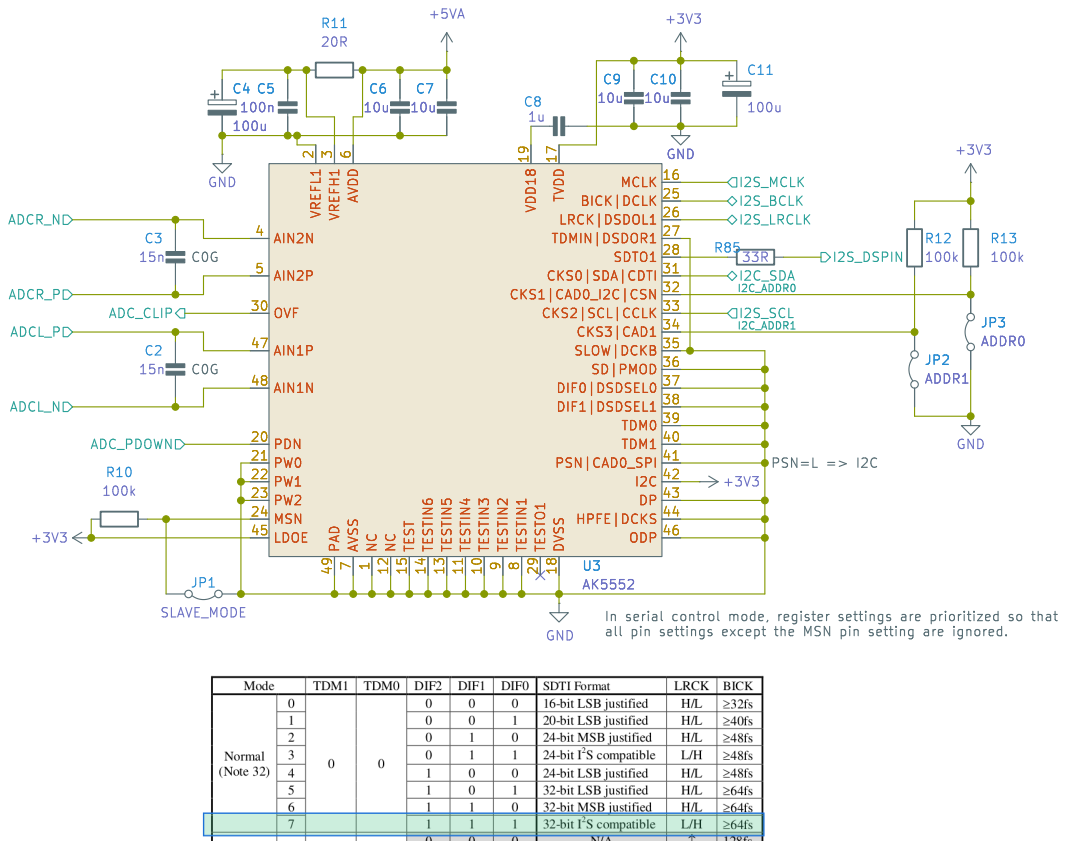
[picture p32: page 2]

2 PDN 20 PW0 21 PW1 22 PW2 23 MSN 24 BICK|DCLK 25

3 OVF 30 CKS0|SDA|CDTI 31 CKS1|CAD0_I2C|CSN 32 CKS2|SCL|CCLK 33 CKS3|CAD1 34 SLOW|DCKB 35 SD|PMOD 36 DIF0|DSDSEL0 37 DIF1|DSDSEL1 38 TDM0 39 AIN2N 4 TDM1 40 PSN|CAD0_SPI 41

1 TESTIN3 10 TESTIN4 11 NC 12 TESTIN5 13 TESTIN6 14 TEST 15 MCLK 16 TVDD 17 DVSS 18 VDD18 19 VREFL1

File: ADC_sch.kicad_sch Sheet: /ADC/ www.hexefx.com

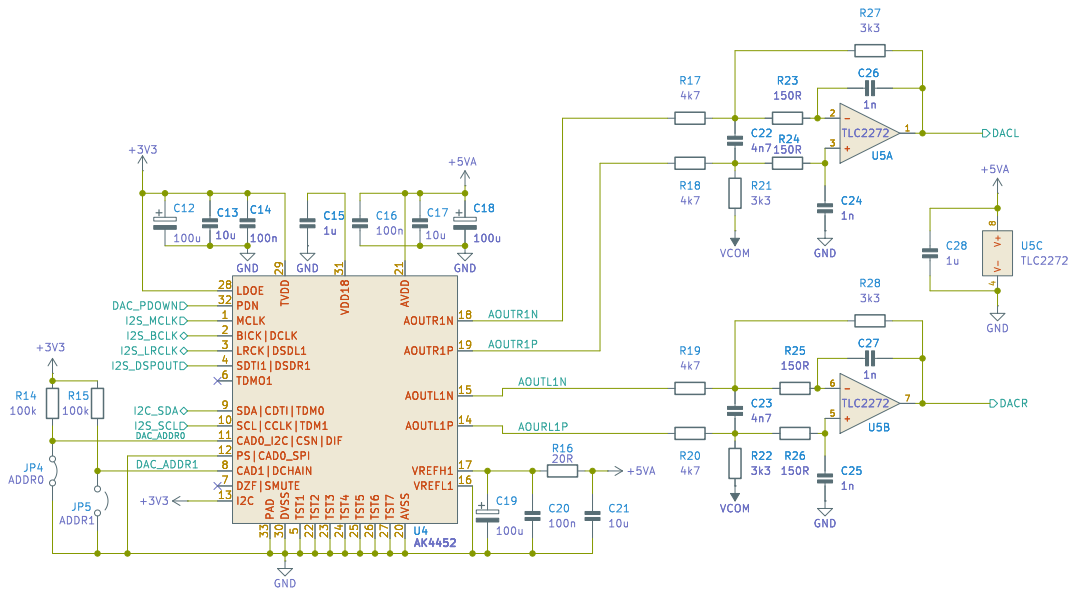
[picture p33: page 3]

5 TDMO1 6 DZF|SMUTE 7 CAD1|DCHAIN 8 SDA|CDTI|TDM0 9 GND

5 TDMO1 6 DZF|SMUTE 7 CAD1|DCHAIN 8 SDA|CDTI|TDM0 9 U4 AK4452 R28

File: DAC.kicad_sch Sheet: /DAC/ www.hexefx.com

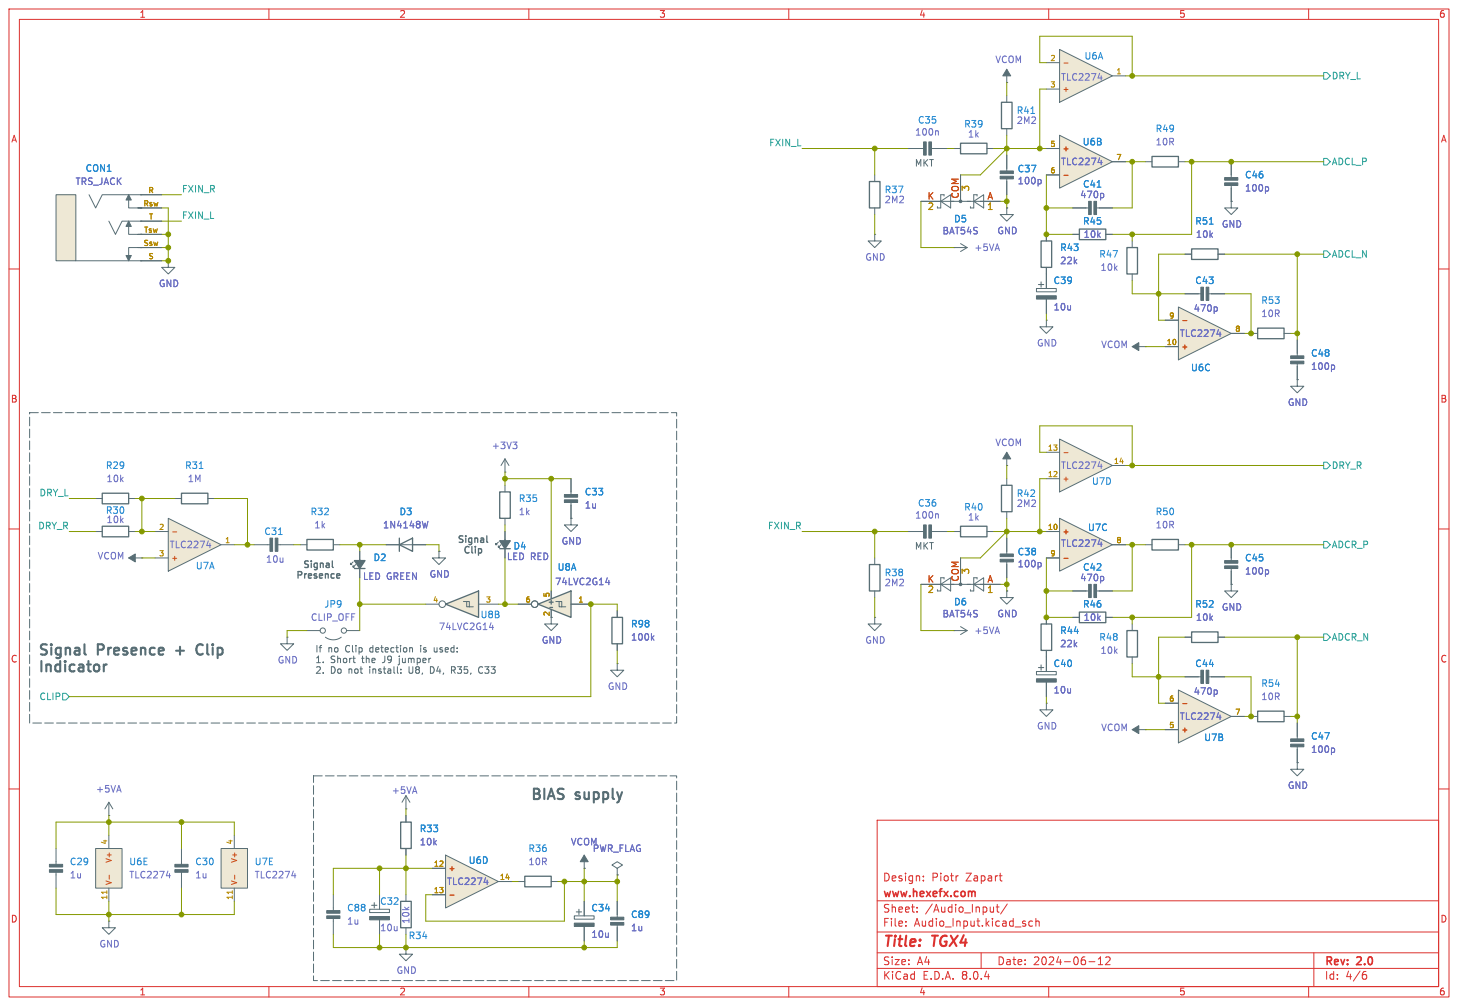
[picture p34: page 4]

File: Audio_Input.kicad_sch Sheet: /Audio_Input/ www.hexefx.com

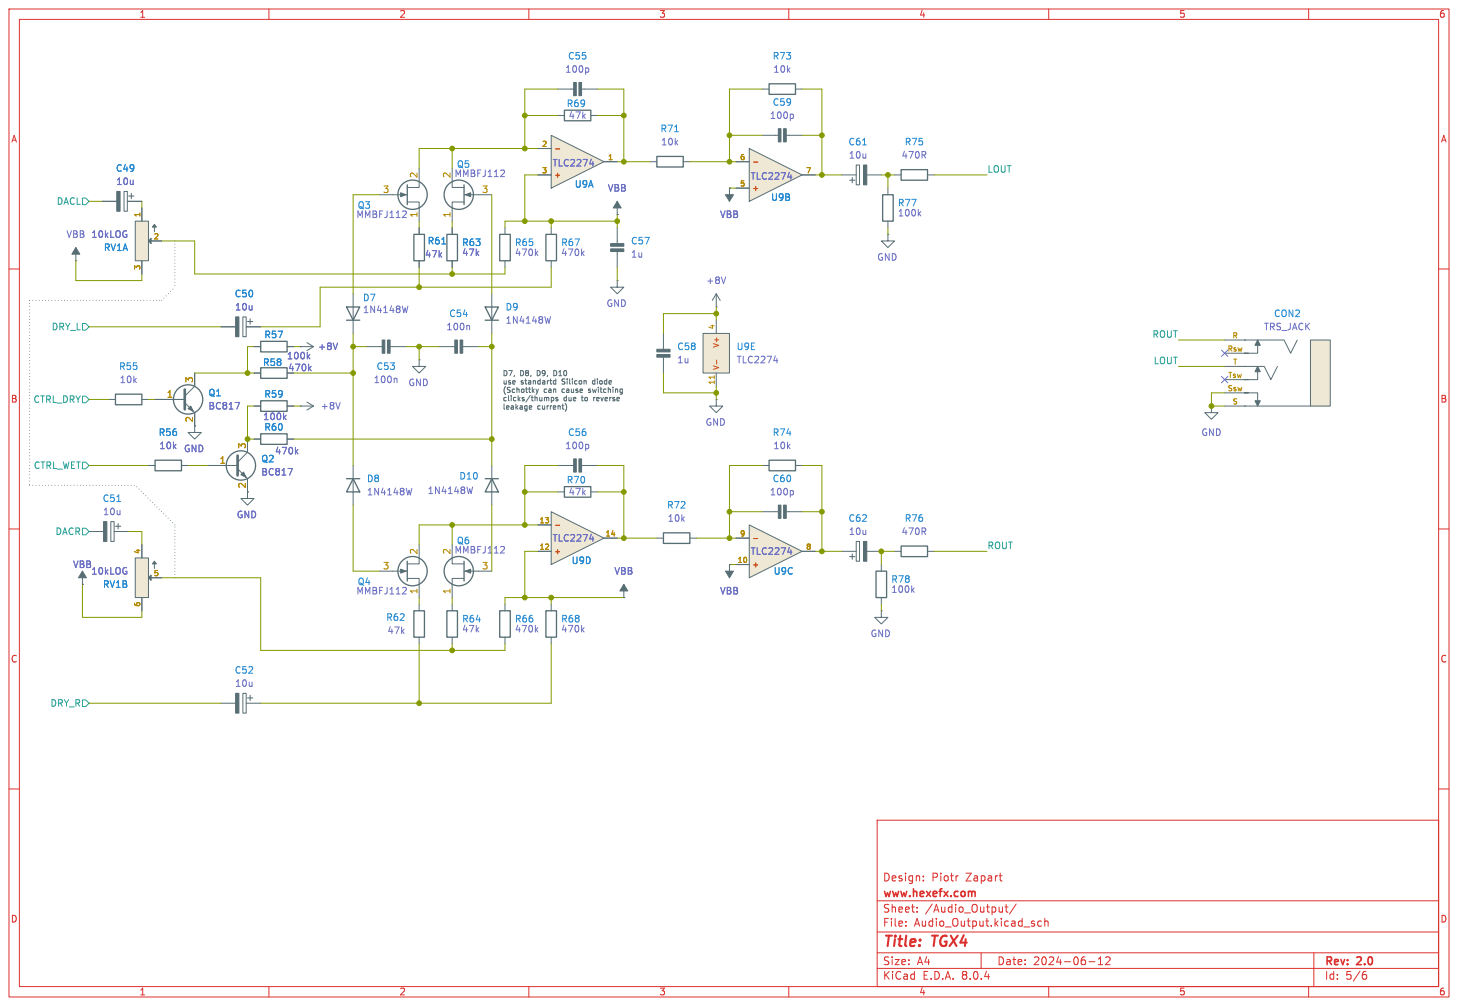
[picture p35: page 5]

File: Audio_Output.kicad_sch Sheet: /Audio_Output/ www.hexefx.com

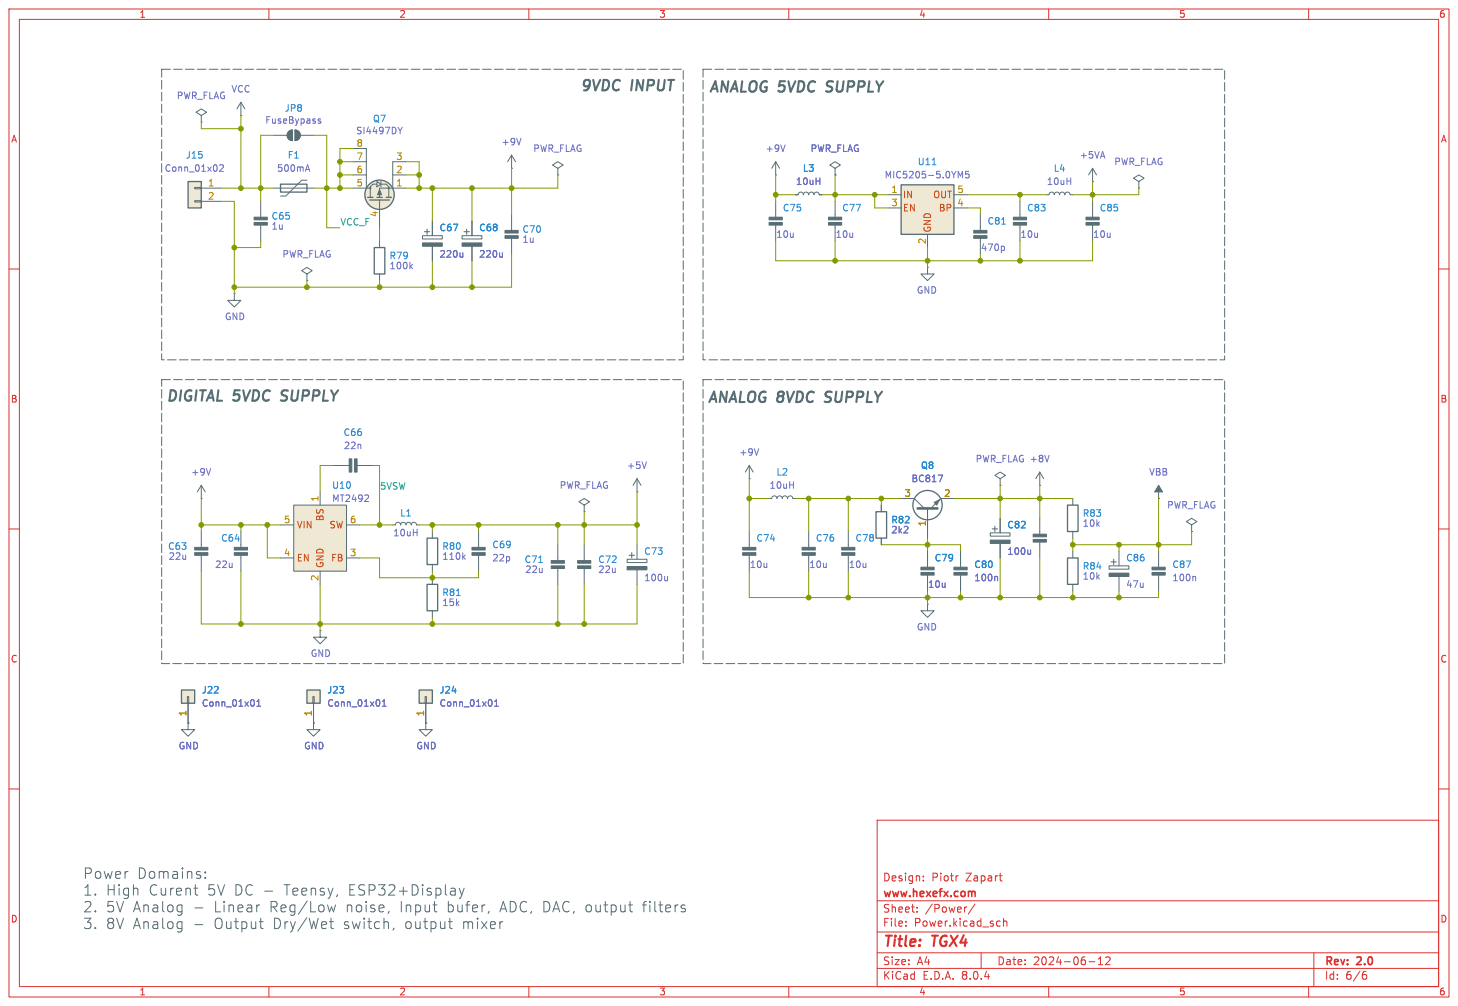
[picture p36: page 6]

2 FB 3 EN 4 VIN 5 SW 6 U10 MT2492 C69

Power Domains:
1. High Curent 5V DC - Teensy, ESP32+Display
2. 5V Analog - Linear Reg/Low noise, Input bufer, ADC, DAC, output filters
3. 8V Analog - Output Dry/Wet switch, output mixer

File: Power.kicad_sch Sheet: /Power/ www.hexefx.com

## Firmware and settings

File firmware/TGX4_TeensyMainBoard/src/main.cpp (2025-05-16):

/**
 * @file main.cpp
 * @author Piotr Zapart
 * @brief Teensy4 guitar amp emulation project
 * 
 * 		required libraries: 
 * 			OpenAudio_ArduinoLibrary: https://github.com/chipaudette/OpenAudio_ArduinoLibrary
 * 			HexeFX_audiolib_F32: https://github.com/hexeguitar/hexefx_audiolib_F32
 * 			
 * 		Neural A Amp modeler based on Seed pedal design by
 * 			Keith Bloemer (GuitarML) https://github.com/GuitarML/Seed
 * 		Wah implementation based on model developed by Transmogrifox
 * 			https://cackleberrypines.net/transmogrifox/src/bela/inductor_wah_C_src/
 * 		
 *  
 * @version 2.0
 * @date 2024-07-26
 * 
 * @copyright Copyright www.hexefx.com (c) 2024
 */


#include <Arduino.h>
#include "debug_log.h"
#include "system.h"
#include "audioComponents.h"
#include "presetSystem.h"
#include "hardware_defs/hardware_defs.h"
#include "console.h"
#include "reverbs.h"
#include "midi.h"	

#if defined(USE_I2S1)
AudioInputI2S_ext_F32			i2s_in;
#elif defined(USE_I2S2)
AudioInputI2S2_F32				i2s_in;
#endif

AudioFilterDCblockerStereo_F32	DCblocker;
AudioSwitchSelectorStereo		inputSwitch;
AudioBasicTempBuffer_F32		InBufferL;
AudioBasicTempBuffer_F32		InBufferR;
AudioEffectCompressorStereo_F32 compressor;
AudioEffectWahMono_F32			wah;
AudioEffectGuitarBooster_F32	booster;
AudioEffectRTNeural_F32			amp;
AudioFilterEqualizer3bandStereo_F32	toneStack;
AudioEffectNoiseGateStereo_F32	gate(InBufferL.dataPtr, InBufferR.dataPtr);
// for Teensy4.0 delay meminit will fail and default to 200ms in DRAM
AudioEffectDelayStereo_F32		echo = AudioEffectDelayStereo_F32(1500, true); // 1 sec delay, buffer in PSRAM;
AudioEffectSpringReverb_F32		reverbSP;
AudioEffectPlateReverb_F32		reverbPL;
// ReverbSC set to use PSRAM will fail to init on Teensy4 and stick in bypass-PASS mode 
AudioEffectReverbSc_F32			reverbSC = AudioEffectReverbSc_F32(true);	
AudioEffectXfaderStereo_F32		xfader_FX;
AudioEffectXfaderStereo_F32		xfader_main;
AudioFilterIRCabsim_F32			cabsim;
AudioFilterBiquadStereo_F32		masterLowCut=AudioFilterBiquadStereo_F32(1); // 1 stage only

AudioEffectGainStereo_F32		masterVol;
#if defined(USE_I2S1)
	AudioOutputI2S_ext_F32    		i2s_out; 
#elif defined(USE_I2S2)
	AudioOutputI2S2_F32     		i2s_out;
#endif
/**
 * -----------------------------------------------------------------------------
 * >>>>> Codec is delcared and defined in the hardware controller class <<<<<<<<
 * -----------------------------------------------------------------------------
 */

// --------------------------------------------------------------
AudioConnection_F32 	cable1(i2s_in, 0, DCblocker, 0);
AudioConnection_F32 	cable2(i2s_in, 1, DCblocker, 1);
AudioConnection_F32 	cable3(DCblocker, 0, inputSwitch, 0);
AudioConnection_F32 	cable4(DCblocker, 1, inputSwitch, 1);
AudioConnection_F32     cable10(inputSwitch, 0, InBufferL, 0); 
AudioConnection_F32     cable11(inputSwitch, 0, compressor, 0);	
AudioConnection_F32     cable12(inputSwitch, 1, InBufferR, 0);
AudioConnection_F32     cable13(inputSwitch, 1, compressor, 1);
AudioConnection_F32     cable14(compressor, 0, wah, 0);
AudioConnection_F32     cable15(compressor, 1, wah, 1);
AudioConnection_F32		cable16(wah, 0, booster, 0);
AudioConnection_F32		cable17(wah, 1, booster, 1);
AudioConnection_F32     cable30(booster, 0, amp, 0);
AudioConnection_F32     cable31(booster, 1, amp, 1);
AudioConnection_F32		cable32(amp, 0, toneStack, 0); 
AudioConnection_F32		cable33(amp, 1, toneStack, 1);
AudioConnection_F32 	cable34(toneStack, 0, gate, 0);
AudioConnection_F32 	cable35(toneStack, 1, gate, 1); 
AudioConnection_F32		cable40(gate, 0, echo, 0);
AudioConnection_F32		cable41(gate, 0, reverbSP, 0);	
AudioConnection_F32		cable42(gate, 0, xfader_main, 0);

AudioConnection_F32		cable50(gate, 1, echo, 1);
AudioConnection_F32		cable51(gate, 1, reverbSP, 1);
AudioConnection_F32		cable52(gate, 1, xfader_main, 1);

AudioConnection_F32		cable60(echo, 0, xfader_FX, 0);
AudioConnection_F32		cable61(echo, 1, xfader_FX, 1);

AudioConnection_F32		cable70(reverbSP, 0, reverbPL, 0);
AudioConnection_F32		cable71(reverbSP, 1, reverbPL, 1);

AudioConnection_F32		cable72(reverbPL, 0, reverbSC, 0);
AudioConnection_F32		cable73(reverbPL, 1, reverbSC, 1);

AudioConnection_F32		cable74(reverbSC, 0, xfader_FX, 2);
AudioConnection_F32		cable75(reverbSC, 1, xfader_FX, 3);

AudioConnection_F32		cable80(xfader_FX, 0, xfader_main, 2);
AudioConnection_F32		cable81(xfader_FX, 1, xfader_main, 3);

AudioConnection_F32     cable82(xfader_main, 0, cabsim, 0);
AudioConnection_F32     cable83(xfader_main, 1, cabsim, 1);

AudioConnection_F32     cable90(cabsim, 0, masterLowCut, 0);
AudioConnection_F32     cable91(cabsim, 1, masterLowCut, 1);

AudioConnection_F32     cable92(masterLowCut, 0, masterVol, 0);
AudioConnection_F32     cable93(masterLowCut, 1, masterVol, 1);

AudioConnection_F32     cable94(masterVol, 0, i2s_out, 0);
AudioConnection_F32     cable95(masterVol, 1, i2s_out, 1);


// --------------------------------------------------------------
void setup()
{
	update_psram_speed(132); // set the PSRAM speed to 132MHz
	DBG_SERIAL.begin(115200);
	AudioMemory_F32(26);
	console_init();

	#if defined(ARDUINO_TEENSY41) || defined (USE_T40_SDIO_ADAPTER)
		if (!SD.begin(BUILTIN_SDCARD))
	#else 
		if (!SD.begin(10)) // standard SPI SD card used on the Teensy Audio Adaptor board
	#endif
		{
			DBG_println("Failed to initialize the SD card!\r\nUsing EEPROM only!"); 
		}
		else 
		{
			DBG_println("SD card initialized."); 
		}
	
	hw.init(); // will init the hardware depending on the configuration
	
	masterVol.phase_inv(hw.phase_invert); // invert output phase if HW requires it
	masterLowCut.setLowShelf(0, 20.0f, -15.0f, 1.0f);
	// software fixes for hardware issues:
	#if defined(USE_HEXEFX_T41GFX)
		i2s_out.set_channel_swap(false);
	#endif
	// set callbacks for USB MIDI
	usbMIDI.setHandleProgramChange(cb_ProgramChange);
	usbMIDI.setHandleNoteOn(cb_NoteOn);
	usbMIDI.setHandleControlChange(cb_ControlChange);
	usbMIDI.setHandleClock(cb_MidiClock);

	presetSystem.setFlagCallback(PRESET_FLAG_BYPASS, [](uint8_t value)
						{ hw.state_set((hw_state_t)!value); presetSystem.resetPreload();});	
	presetSystem.setFlagCallback(PRESET_FLAG_INSELECT, [](uint8_t value)
						{ inputSwitch.setMode((AudioSwitchSelectorStereo::selector_mode_t)value);});
	presetSystem.setFlagCallback(PRESET_FLAG_COMP_EN, [](uint8_t value)
						{ compressor.bypass_set(value ? false : true); });
	presetSystem.setFlagCallback(PRESET_FLAG_WAH_EN, [](uint8_t value)
						{ wah.bypass_set(value ? false : true); });
	presetSystem.setFlagCallback(PRESET_FLAG_WAH_MODEL, [](uint8_t value)
						{ wah.setModel((wahModel_t)value); });
	presetSystem.setFlagCallback(PRESET_FLAG_BOOST_EN, [](uint8_t value)
						{ booster.bypass_set(value ? false : true); });
	presetSystem.setFlagCallback(PRESET_FLAG_OCTAVE_EN, [](uint8_t value)
						{ booster.octave_set(value); });
	presetSystem.setFlagCallback(PRESET_FLAG_AMPMODEL_NO, [](uint8_t value)
						{ amp.changeModel(value);});
	presetSystem.setFlagCallback(PRESET_FLAG_DOUBLER_EN, [](uint8_t value)
						{ cabsim.doubler_set(value); });
	presetSystem.setFlagCallback(PRESET_FLAG_CABIR_NO, [](uint8_t value)
						{ cabsim.ir_load(value); });
	presetSystem.setFlagCallback(PRESET_FLAG_DELAY_EN, [](uint8_t value)
						{ echo.bypass_set(value ? false : true); });
	presetSystem.setFlagCallback(PRESET_FLAG_REVBTYPE, [](uint8_t value)
						{ reverbs_set((active_reverb_e)value, reverb_getBypass()); });
	presetSystem.setFlagCallback(PRESET_FLAG_REVB_EN, [](uint8_t value)
						{ reverb_setBypass(value ? false : true); });
	presetSystem.setFlagCallback(PRESET_FLAG_DELAY_FREEZE_EN, [](uint8_t value)
						{ echo.freeze(value); });
	presetSystem.setFlagCallback(PRESET_FLAG_REVB_FREEZE_EN, [](uint8_t value)
						{ reverb_setFreeze(value); });
	// presetSystem.setFlagCallback(PRESET_FLAG_POT1_ASSIGN, [](uint8_t value)
	// 					{ return; }); //TODO:
	// presetSystem.setFlagCallback(PRESET_FLAG_POT2_ASSIGN, [](uint8_t value)
	// 					{ return; }); //TODO:
	// presetSystem.setFlagCallback(PRESET_FLAG_POT3_ASSIGN, [](uint8_t value)
	// 					{ return; }); //TODO:
	// presetSystem.setFlagCallback(PRESET_FLAG_EXP_ASSIGN, [](uint8_t value)
	// 					{ return; }); //TODO:
	presetSystem.setFlagCallback(PRESET_FLAG_FT1_ASSIGN, [](uint8_t value)
	 					{  hw.led_set(1, presetSystem.getFootswAssignFlagValue(value) ? HW_STATE_ON : HW_STATE_OFF); });
	presetSystem.setFlagCallback(PRESET_FLAG_FT2_ASSIGN, [](uint8_t value)
	 					{  hw.led_set(2, presetSystem.getFootswAssignFlagValue(value) ? HW_STATE_ON : HW_STATE_OFF); });
	presetSystem.setFlagCallback(PRESET_FLAG_DRYSIG, [](uint8_t value)
						{ hw.dry_set((hw_state_t)value); });
	// param change callbacks
	presetSystem.setParamCallback(PRESET_PARAM_COMP_PREGAIN, [](float32_t value)
						{ compressor.setPreGain_normalized(value); });
	presetSystem.setParamCallback(PRESET_PARAM_COMP_THRES, [](float32_t value)
						{ compressor.setThresh_normalized(value); });
	presetSystem.setParamCallback(PRESET_PARAM_COMP_RATIO, [](float32_t value)
						{ compressor.setCompressionRatio_normalized(value); });
	presetSystem.setParamCallback(PRESET_PARAM_COMP_ATTACK, [](float32_t value)
						{ compressor.setAttack_normalized(value); });
	presetSystem.setParamCallback(PRESET_PARAM_COMP_RELEASE, [](float32_t value)
						{ compressor.setRelease_normalized(value); });
	presetSystem.setParamCallback(PRESET_PARAM_COMP_POSTGAIN, [](float32_t value)
						{ compressor.setPostGain_normalized(value); });
	presetSystem.setParamCallback(PRESET_PARAM_WAH_FREQ, [](float32_t value)
						{ wah.setFreq(value); });
	presetSystem.setParamCallback(PRESET_PARAM_WAH_MIX, [](float32_t value)
						{ wah.setMix(value); });
	presetSystem.setParamCallback(PRESET_PARAM_BOOST_DRIVE, [](float32_t value)
						{ booster.drive_normalized(value); });
	presetSystem.setParamCallback(PRESET_PARAM_BOOST_BOTTOM, [](float32_t value)
						{ booster.bottom(value); });
	presetSystem.setParamCallback(PRESET_PARAM_BOOST_PRESENCE, [](float32_t value)
						{ booster.tone(value); });
	presetSystem.setParamCallback(PRESET_PARAM_BOOST_MIX, [](float32_t value)
						{ booster.mix(value); });
	presetSystem.setParamCallback(PRESET_PARAM_AMP_GATE, [](float32_t value)
						{ gate.setThreshold_normalized(value); });
	presetSystem.setParamCallback(PRESET_PARAM_AMP_GAIN, [](float32_t value)
						{ amp.gain(value); });
	presetSystem.setParamCallback(PRESET_PARAM_AMP_BASS, [](float32_t value)
						{ toneStack.bass(value); });
	presetSystem.setParamCallback(PRESET_PARAM_AMP_MID, [](float32_t value)
						{ toneStack.mid(value); });
	presetSystem.setParamCallback(PRESET_PARAM_AMP_TREBLE, [](float32_t value)
						{ toneStack.treble(value); });
	presetSystem.setParamCallback(PRESET_PARAM_AMP_FXMIX, [](float32_t value)
						{ xfader_main.mix(value); });
	presetSystem.setParamCallback(PRESET_PARAM_DELAY_TIME, [](float32_t value)
						{ echo.time(value); });
	presetSystem.setParamCallback(PRESET_PARAM_DELAY_INERTIA, [](float32_t value)
						{ echo.inertia(value); });
	presetSystem.setParamCallback(PRESET_PARAM_DELAY_REPEATS, [](float32_t value)
						{ echo.feedback(value); });
	presetSystem.setParamCallback(PRESET_PARAM_DELAY_MIX, [](float32_t value)
						{ echo.mix(value); });
	presetSystem.setParamCallback(PRESET_PARAM_DELAY_HICUT, [](float32_t value)
						{ echo.treble_cut(value); });
	presetSystem.setParamCallback(PRESET_PARAM_DELAY_LOWCUT, [](float32_t value)
						{ echo.bass_cut(value); });
	presetSystem.setParamCallback(PRESET_PARAM_DELAY_MIX, [](float32_t value)
						{ echo.mix(value); });
	presetSystem.setParamCallback(PRESET_PARAM_DELAY_TREBLE, [](float32_t value)
						{ echo.treble(value); });
	presetSystem.setParamCallback(PRESET_PARAM_DELAY_BASS, [](float32_t value)
						{ echo.bass(value); });
	presetSystem.setParamCallback(PRESET_PARAM_DELAY_MODRATE, [](float32_t value)
						{ echo.mod_rate(value); });
	presetSystem.setParamCallback(PRESET_PARAM_DELAY_MODDEPTH, [](float32_t value)
						{ echo.mod_depth(value); });
	presetSystem.setParamCallback(PRESET_PARAM_REVERBPL_SIZE, [](float32_t value)
						{ reverbPL.size(value); });
	presetSystem.setParamCallback(PRESET_PARAM_REVERBPL_DIFF, [](float32_t value)
						{ reverbPL.diffusion(value); });
	presetSystem.setParamCallback(PRESET_PARAM_REVERBPL_MIX, [](float32_t value)
						{ reverbPL.mix(value); });
	presetSystem.setParamCallback(PRESET_PARAM_REVERBPL_BASSCUT, [](float32_t value)
						{ reverbPL.lodamp(value); });
	presetSystem.setParamCallback(PRESET_PARAM_REVERBPL_TREBLECUT, [](float32_t value)
						{ reverbPL.hidamp(value); });
	presetSystem.setParamCallback(PRESET_PARAM_REVERBPL_TREBLE, [](float32_t value)
						{ reverbPL.lowpass(1.0f - value); });
	presetSystem.setParamCallback(PRESET_PARAM_REVERBPL_BASS, [](float32_t value)
						{ reverbPL.hipass(1.0f - value); });
	presetSystem.setParamCallback(PRESET_PARAM_REVERBPL_BLEEDIN, [](float32_t value)
						{ reverbPL.freezeBleedIn(value); });
	presetSystem.setParamCallback(PRESET_PARAM_REVERBPL_PITCH, [](float32_t value)
						{ reverbPL.pitchNormalized(value); });
	presetSystem.setParamCallback(PRESET_PARAM_REVERBPL_PITCHMIX, [](float32_t value)
						{ reverbPL.pitchMix(value); });
	presetSystem.setParamCallback(PRESET_PARAM_REVERBPL_SHIMMER, [](float32_t value)
						{ reverbPL.shimmer(value); });
	presetSystem.setParamCallback(PRESET_PARAM_REVERBPL_PITCHSHIMM, [](float32_t value)
						{ reverbPL.shimmerPitchNormalized(value); });
	presetSystem.setParamCallback(PRESET_PARAM_REVERBSC_TIME, [](float32_t value)
						{ reverbSC.feedback(value); });
	presetSystem.setParamCallback(PRESET_PARAM_REVERBSC_MIX, [](float32_t value)
						{ reverbSC.mix(value); });
	presetSystem.setParamCallback(PRESET_PARAM_REVERBSC_LOWPASSF, [](float32_t value)
						{ reverbSC.lowpass(value); });
	presetSystem.setParamCallback(PRESET_PARAM_REVERBSP_TIME, [](float32_t value)
						{ reverbSP.time(value); });
	presetSystem.setParamCallback(PRESET_PARAM_REVERBSP_MIX, [](float32_t value)
						{ reverbSP.mix(value); });
	presetSystem.setParamCallback(PRESET_PARAM_REVERBSP_BASSCUT, [](float32_t value)
						{ reverbSP.bass_cut(value); });
	presetSystem.setParamCallback(PRESET_PARAM_REVERBSP_TREBLECUT, [](float32_t value)
						{ reverbSP.treble_cut(value); });
	presetSystem.setParamCallback(PRESET_PARAM_MASTER_VOLUME, [](float32_t value)
						{ masterVol.setGain(value); });
	presetSystem.setParamCallback(PRESET_PARAM_MASTER_PAN, [](float32_t value)
						{ masterVol.setPan(value); });
	presetSystem.setParamCallback(PRESET_PARAM_DELAY_REVERB_MIX, [](float32_t value)
						{ xfader_FX.mix(value); });
	presetSystem.setParamCallback(PRESET_PARAM_MASTER_LOWCUT, [](float32_t value)
						{ masterLowCut.makeupGain(1.0f + value*0.5f);
						  masterLowCut.setLowShelf(0, MASTER_LOWCUT_FMIN +\
						   value*MASTER_LOWCUT_FMAX, -15.0f, 1.0f); });
	delay(300);				// add a bit of delay before initializine the SD card. Some pedalboard power supplies slowly ramp up the voltage.
	presetSystem.init(); // loads the last used preset - needs the callbacks defined, hence placed here
	
	gui.init();	// init gui after the preset has been loaded
}
// --------------------------------------------------------------
void loop()
{
	 if (CrashReport)
	{
		Serial.print(CrashReport);
		delay(3000);
	}
	usbMIDI.read();
	console_process();
	presetSystem.process();
	hw.process();
	gui.process();
}

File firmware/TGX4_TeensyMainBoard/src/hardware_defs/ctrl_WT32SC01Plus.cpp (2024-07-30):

#include "ctrl_WT32SC01Plus.h"
#include "debug_log.h"
// #include "hw_proto.h"
#include "console.h"
#include "presetSystem.h"

static void i2cS_onReceive(int numBytes);
static void i2cS_onRequest();

#if defined (USE_CONTROL_WT32SC01PLUS)
	Control_WT32SC01PLUS gui;
#endif

Control_WT32SC01PLUS* selfPtr = NULL;

FLASHMEM void Control_WT32SC01PLUS::init(TwoWire* i2cBus, uint8_t addr, uint8_t INTgpio)
{
	selfPtr = this;
	bus = i2cBus;
	i2cS_addr = addr;
	guiINT_pin = INTgpio;

	pinMode(guiINT_pin, OUTPUT);
	digitalWrite(guiINT_pin, LOW);
	bus->begin(i2cS_addr);
	bus->onReceive(i2cS_onReceive);
	bus->onRequest(i2cS_onRequest);
	delay(200);
	gui_state = GUI_STATE_IDLE;
	presetSystem.triggerFullGuiUpdate();
}

void Control_WT32SC01PLUS::process(void)
{
	float32_t tmpf;
	uint32_t t_now = millis();
	static uint32_t t_last = 0;
	char* u8ptr;
	switch(gui_state)
	{
		case GUI_STATE_IDLE: 
			if (t_now - t_last > 100)
			{
				flagChangeMask = presetSystem.getFlagsChangeMask();
				paramChangeMask = presetSystem.getParamsChangeMask();
				if ((flagChangeMask || paramChangeMask))
				{
					gui_state = GUI_STATE_WAIT_4_CMD;
					signalChange();
					presetSystem.resetChangeMask();
				}
				t_last = t_now;
			}
			break;
		case GUI_STATE_WAIT_4_CMD: break;
		case GUI_STATE_CMD_RECEIVED:
			cmd = (gui_cmd_t)i2cS_data[0];
			switch (cmd)
			{
				case GUI_CMD_NOP: break;
				case GUI_CMD_REQ_STATE:
					sendChangeMasks();
					gui_state = GUI_STATE_IDLE;
					break;
				case GUI_CMD_SET_FLAG: // ----------------------------------------------------------------
					DBG_println("cmd set flag");
					// Cmd (1 byte) + flag number (1 byte) + flag value (1 byte)
					if(bytesReceived != 3) 
					{
						gui_state = GUI_STATE_ERROR_NO_DATA;
						break;
					}
					if (i2cS_data[1] < PRESET_FLAG_LAST) // [1] holds the flag index [2] flag value
					{
						presetSystem.updateFlag((preset_paramFlag_t)i2cS_data[1], i2cS_data[2], false); // no need to signal back to the ESP
						//DBG_printf("Flag %d updated with value %d\r\n", i2cS_data[1], i2cS_data[2]);
					}
					i2cS_data[0] = i2cS_addr;
					i2cS_dataRequestLength = 1;					
					break;
				case GUI_CMD_SET_FLAGS: // ----------------------------------------------------------------
					DBG_println("cmd set flags");
					// Cmd (1 byte) + all flags
					if(bytesReceived != 1 + sizeof(preset_flags_t)) 
					{
						gui_state = GUI_STATE_ERROR_NO_DATA;
						break;
					}
					updateFlags(&i2cS_data[1], false);
					i2cS_data[0] = i2cS_addr;
					i2cS_dataRequestLength = 1;
					gui_state = GUI_STATE_IDLE;
					break;					
				case GUI_CMD_SET_PARAM:// ----------------------------------------------------------------
					DBG_println("cmd set param");
					// cmd + param number + param value = 3 bytes
					if(bytesReceived != 3) 
					{
						gui_state = GUI_STATE_ERROR_NO_DATA;
						break;
					}
					if (i2cS_data[1] < PRESET_PARAM_LAST)
					{
						tmpf = (float32_t)i2cS_data[2] / guiSliderMax;
						presetSystem.updateFXparam((preset_param_t)i2cS_data[1], tmpf, false);
					}
					i2cS_data[0] = i2cS_addr;
					i2cS_dataRequestLength = 1;
					gui_state = GUI_STATE_IDLE;
					break;
				case GUI_CMD_SET_PARAMS:	// ----------------------------------------------------------------
					DBG_println("cmd set all params");

					i2cS_data[0] = i2cS_addr;
					i2cS_dataRequestLength = 1;
					gui_state = GUI_STATE_IDLE;
					break;					
				case GUI_CMD_CHANGE_PRESET:
					DBG_println("cmd change preset");
					// cmd + preset num (7bit)
					if(bytesReceived != 2) 
					{
						gui_state = GUI_STATE_ERROR_NO_DATA;
						break;
					}
					if (presetSystem.getSDstatus()) // all 128 presets available
					{
						presetSystem.load(i2cS_data[1] & 0x7F);
					}
					else 				// only 8 in EEPROM
					{
						presetSystem.load(i2cS_data[1] & 0x07);
					}
					DBG_printf("Preset changed to %d\r\n", i2cS_data[1]);
					sendPresetData();
					break;
				case GUI_CMD_SAVE_PRESET: // ----------------------------------------------------------------
					DBG_println("cmd save preset");	
					// ESP send a new name for the preset upon saving
					if(bytesReceived != 1 + member_size(preset_t, name)) 
					{
						gui_state = GUI_STATE_ERROR_NO_DATA;
						break;
					}	
					presetSystem.setName((char*)&i2cS_data[1]);
					presetSystem.save();
					i2cS_data[0] = i2cS_addr;
					i2cS_dataRequestLength = 1;
					gui_state = GUI_STATE_IDLE;
					DBG_printf("Preset %d saved: %s\r\n", 
							presetSystem.getCurrentIdx(), presetSystem.getName());
					break;
				case GUI_CMD_PRESET_RELOAD:
					DBG_println("cmd preset reload");
					presetSystem.load(presetSystem.getCurrentIdx()); // restore the preset settings
					sendPresetData();
					gui_state = GUI_STATE_IDLE;
					break;
				case GUI_CMD_GET_PRESET: // ----------------------------------------------------------------
					// reply: preset data
					DBG_println("cmd get preset");
					sendPresetData();
					gui_state = GUI_STATE_IDLE;
					break;
				case GUI_CMD_GET_PRESET_NAME:
					DBG_println("cmd get preset name");
					// cmd + presetNo, reply = 16byte string
					if(bytesReceived != 2) 
					{
						gui_state = GUI_STATE_ERROR_NO_DATA;
						break;
					}	
					u8ptr = presetSystem.getName(i2cS_data[1]);
					memcpy(i2cS_data, u8ptr, member_size(preset_t, name));
					i2cS_dataRequestLength = member_size(preset_t, name);
					signalChange();
					break;	
				case GUI_CMD_GET_FLAGS:
					DBG_println("cmd get all flags");
					sendFlags();
					gui_state = GUI_STATE_IDLE;				
					break;
				case GUI_CMD_GET_PARAMS:
					DBG_println("cmd get params");
					sendParams();
					gui_state = GUI_STATE_IDLE;					
					break;
				case GUI_CMD_GET_PARAM: // ----------------------------------------------------------------
					DBG_println("cmd get param");
					// cmd + param index, reply = 1 byte (float scaled to uint8_t)
					if(bytesReceived != 2) 
					{
						gui_state = GUI_STATE_ERROR_NO_DATA;
						break;
					}
					if(i2cS_data[1] < PRESET_PARAM_LAST)
					{
						i2cS_data[0] = (uint8_t)(presetSystem.getFXparam((preset_param_t)i2cS_data[1]) * guiSliderMax);
						i2cS_dataRequestLength = 1;
						signalChange();						
						gui_state = GUI_STATE_IDLE;
					}
					else
					{
						gui_state = GUI_STATE_ERROR_WRONG_PARAM;
					}					
					break;
				case GUI_CMD_PRESET_UP: // ----------------------------------------------------------------
					DBG_println("cmd preset up");
					presetSystem.load_next();
					sendPresetData();
					gui_state = GUI_STATE_IDLE;
					break;
				case GUI_CMD_PRESET_DOWN: // ----------------------------------------------------------------
					DBG_println("cmd preset down");
					presetSystem.load_previous();
					sendPresetData();
					gui_state = GUI_STATE_IDLE;		
					break;
			}
			cmd = GUI_CMD_NOP;
			break;
		case GUI_STATE_ERROR_NO_DATA:
			DBG_println("Gui command error! None or too few data bytes received.");
			gui_last_error = gui_state;
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

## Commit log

2024-07-30 major update to 2.0
    [ADC_sch.kicad_sch, Audio_Input.kicad_sch, Audio_Output.kicad_sch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]
2024-12-13 Teensy4.0 bug fixes
2024-12-13 Front panel, bug fixes
    [TGX4_Panel.kicad_pcb, TGX4_Panel.kicad_sch]
2025-01-13 library name fix, updates
    [hw_hexefx_t40gfx.h, hw_hexefx_t41gfx.h, hw_hexefx_tgx4.h]
2025-05-16 fix hw led control while loading a new preset
    [hw_hexefx_t40gfx.h, hw_hexefx_t41gfx.h, hw_hexefx_tgx4.cpp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]
